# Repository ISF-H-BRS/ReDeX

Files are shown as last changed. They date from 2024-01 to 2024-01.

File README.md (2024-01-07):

# ReDeX: Water Purification Measurements

## Introduction

This repository contains a public archive of electronics, firmware and software developed as part of the project [ReDeX](https://www.h-brs.de/de/entwicklung-einer-reduktiven-behandlungsmethode-zur-entfernung-von-desinfektionsnebenprodukten-und) that was conducted at Bonn-Rhein-Sieg University of Applied Sciences from 2019 to 2022.

The goal of this sub-project was to develop a sensor network allowing various parameters inside a water purification system to be monitored and analyzed in order to gain a better understanding of the chemical and physical processes involved.

The system is composed of sensor nodes which can be used either as standalone devices connected to a PC over USB or as a sensor network accessed over TCP/IP via a central hub. Every sensor provides complete galvanic isolation in order to prevent any possibility of cross-currents which could potentially invalidate measurements.

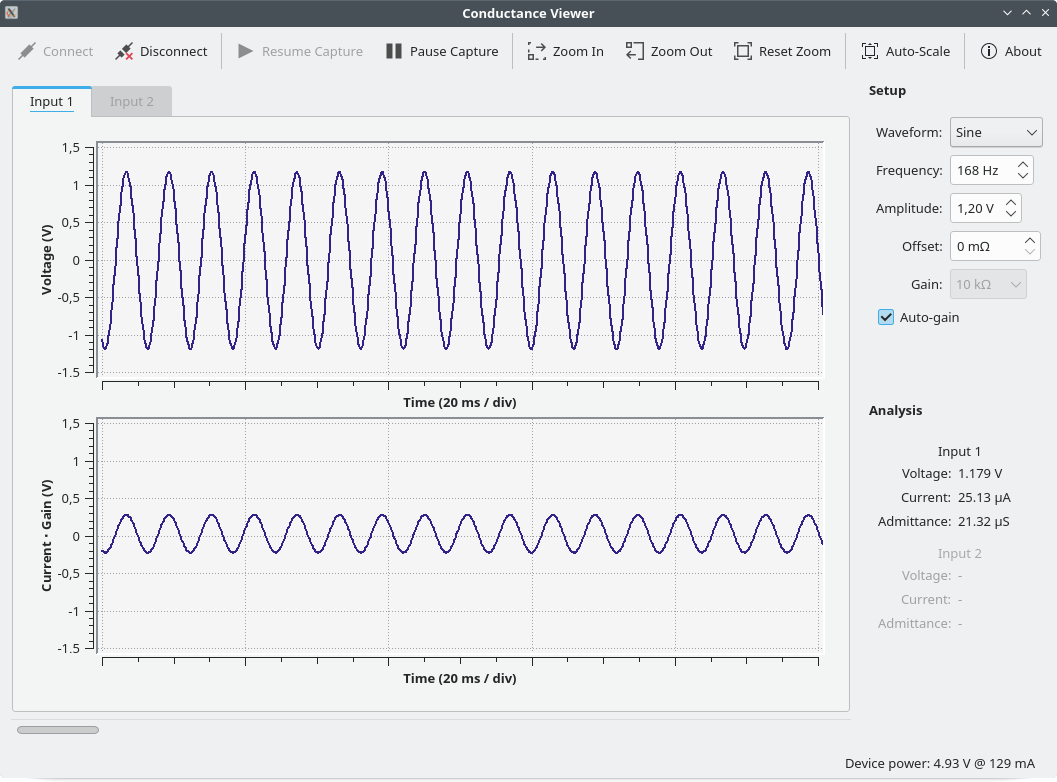
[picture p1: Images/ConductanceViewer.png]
ConductanceViewer


The parameters that can be measured include conductance, pH/ORP levels and temperature. In addition a potentiostat for cyclic voltammetry was developed, providing a compliance voltage of ±4 V and a dynamic range of approx. 1 pA to 10 mA.

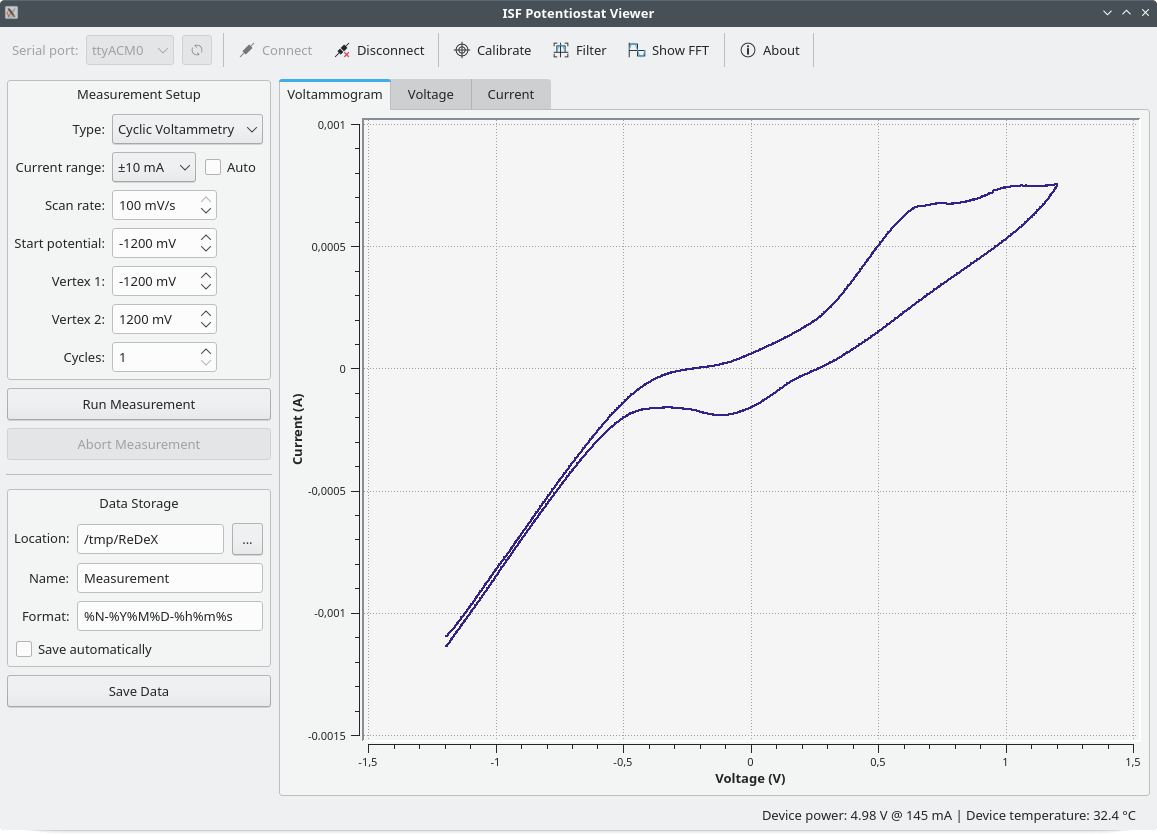
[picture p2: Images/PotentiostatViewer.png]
PotentiostatViewer


Every sensor node has a corresponding user software providing a GUI for individual measurements. The complete sensor network can be accessed via the central hub by means of a shared library with optional LabVIEW integration.

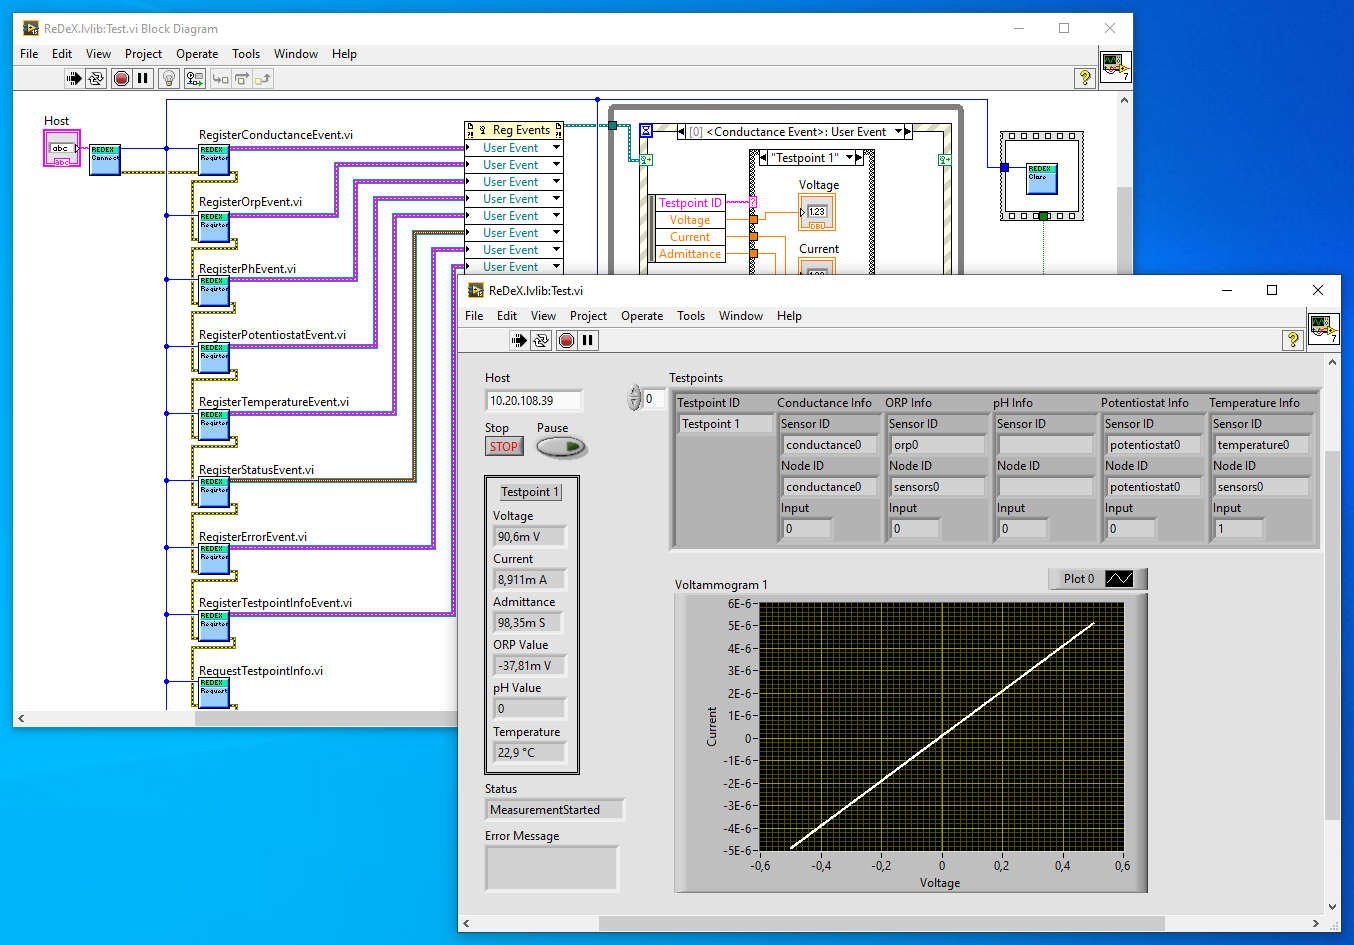
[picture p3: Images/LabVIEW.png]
LabVIEW


## License

All source code for the software and firmware components (including the LabVIEW code) is licensed under the terms of the GNU General Public License (GPL). All schematics and CAD files for EAGLE and FreeCAD are licensed under the terms of the Creative Commons Attribution-ShareAlike International Public License (CC BY-SA). See COPYING in the respective subdirectories for details.

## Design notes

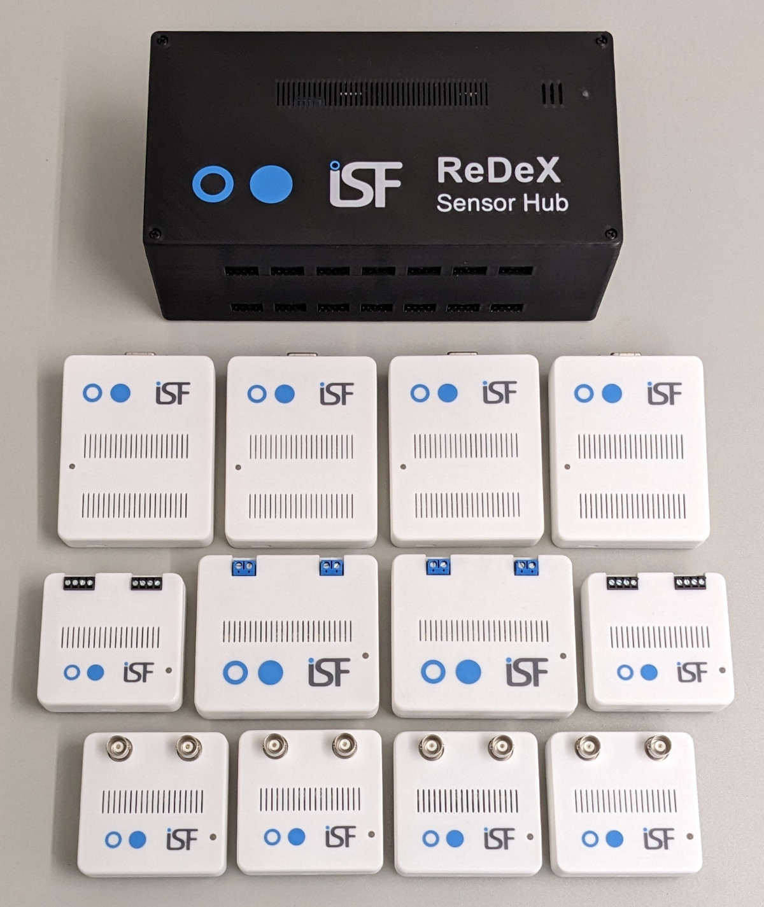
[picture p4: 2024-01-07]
Images/Overview.jpg

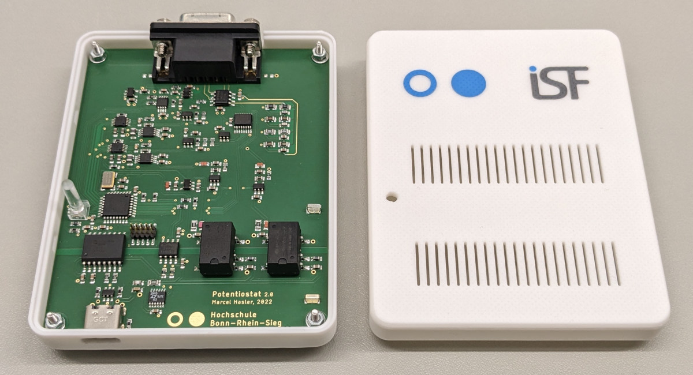
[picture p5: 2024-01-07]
Images/Potentiostat2.jpg

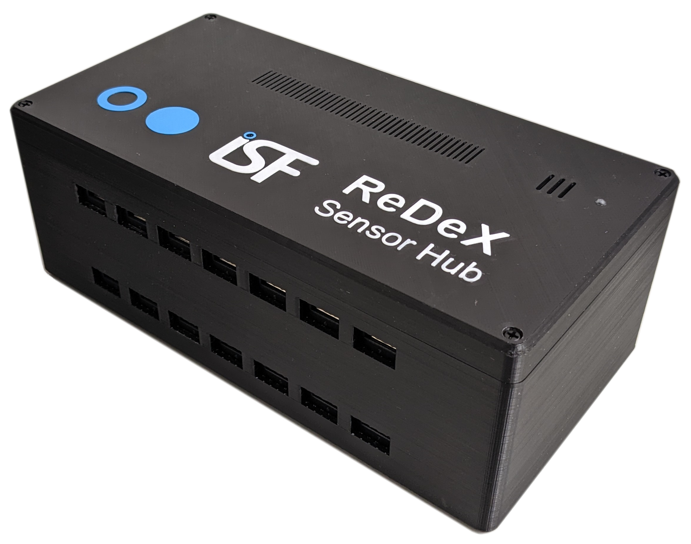
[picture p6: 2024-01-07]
Images/HubFront.jpg

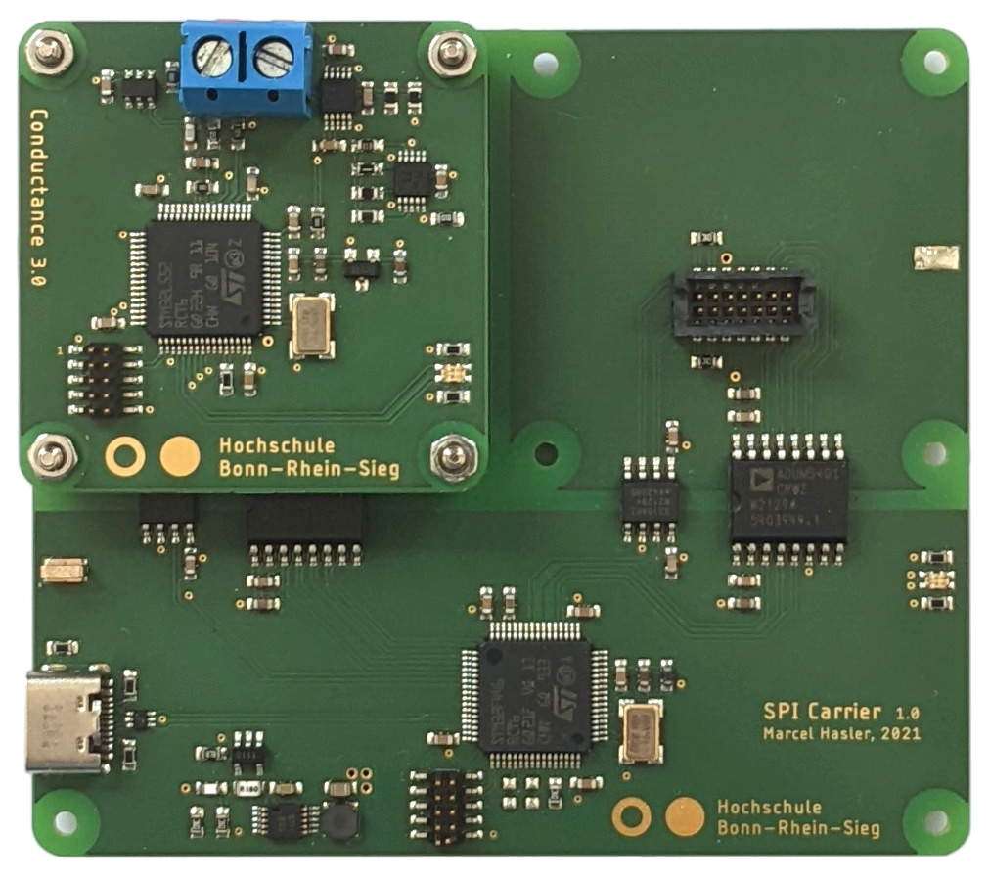
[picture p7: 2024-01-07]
Images/ConductanceBoard.jpg

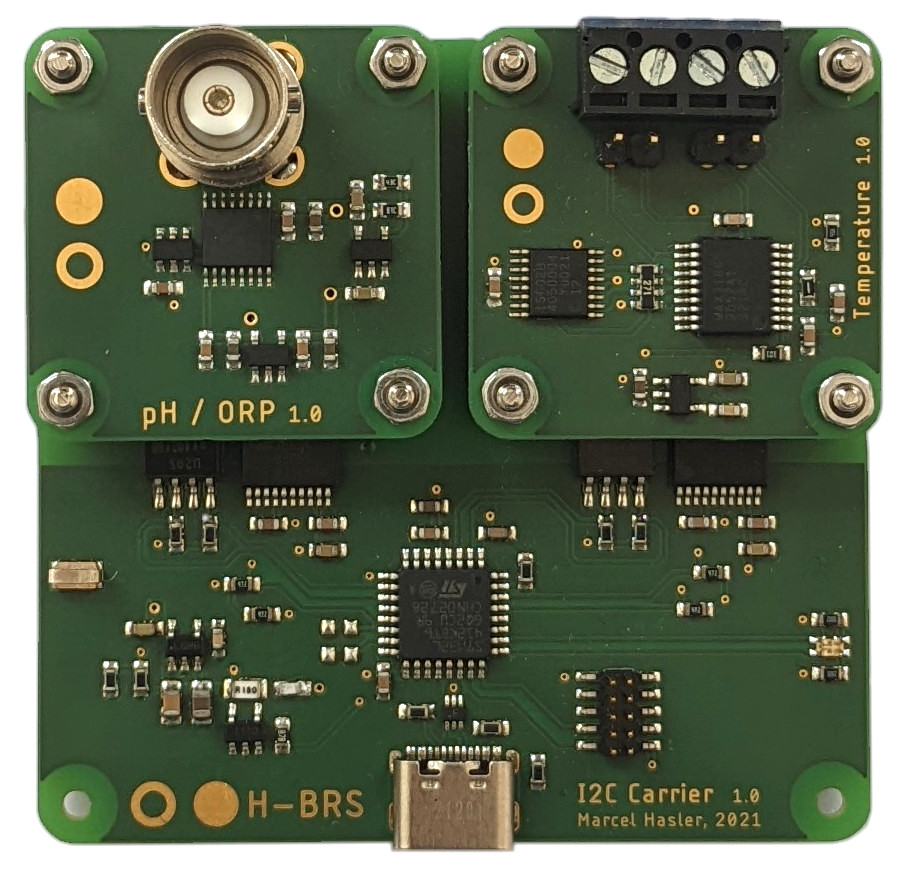
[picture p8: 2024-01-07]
Images/SensorBoard.jpg

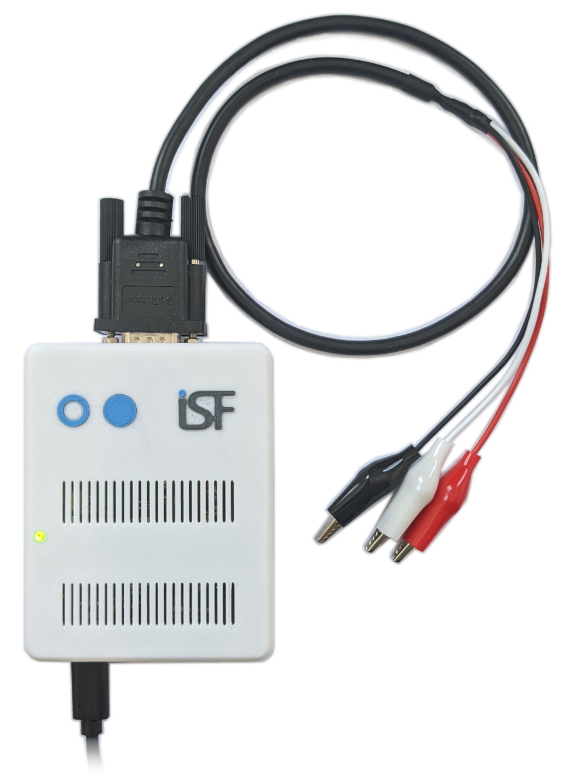
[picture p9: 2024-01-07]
Images/Potentiostat1.jpg

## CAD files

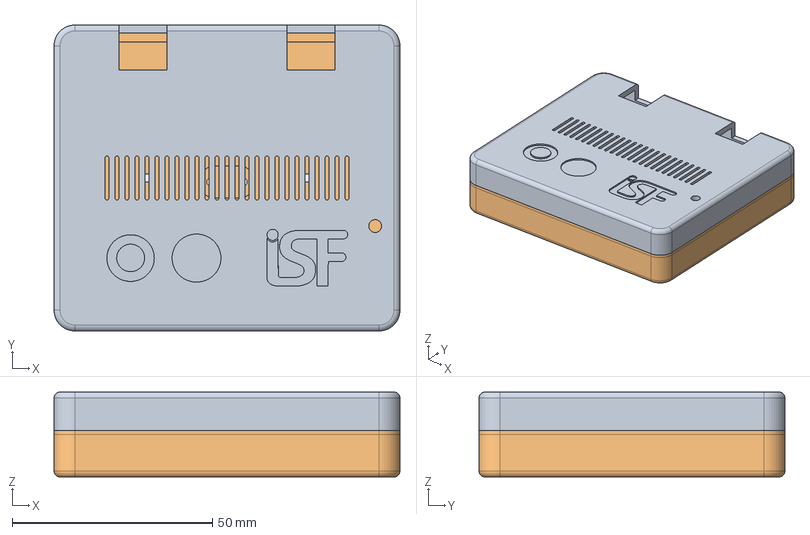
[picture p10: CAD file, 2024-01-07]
FreeCAD/Conductance/Conductance.FCStd
86.4 x 76.4 x 21.2 mm
TopLogosCut
BottomMountholeCut

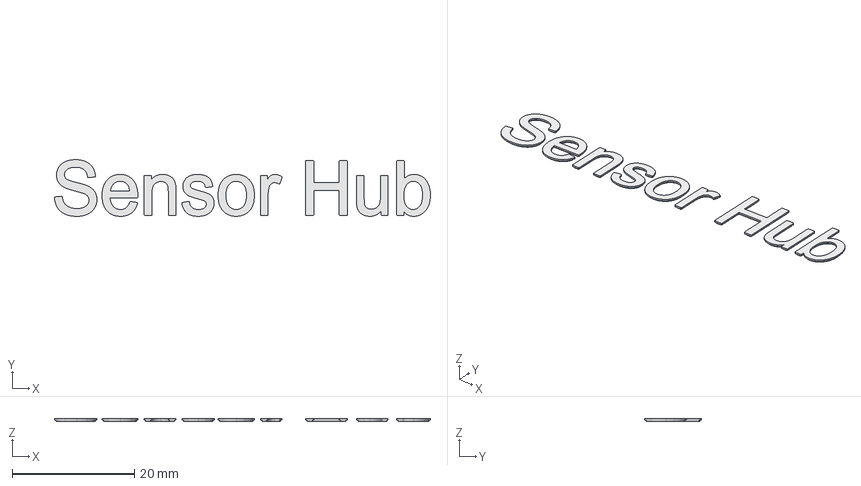
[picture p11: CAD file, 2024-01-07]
FreeCAD/Hub/Label.FCStd
61.5 x 9.29 x 0.48 mm

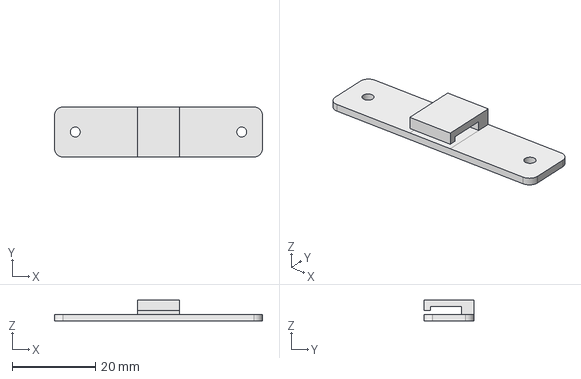
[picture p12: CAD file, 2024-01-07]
FreeCAD/Other/NodeMount.FCStd
50.0 x 12.0 x 5.00 mm

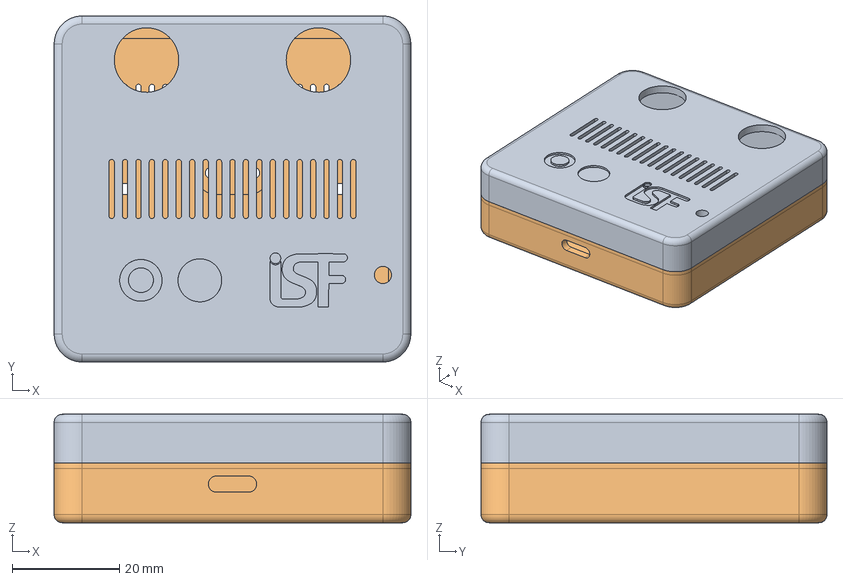
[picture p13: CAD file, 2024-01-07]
FreeCAD/pH/pH.FCStd
66.4 x 64.4 x 20.2 mm
TopLogosCut
BottomLockCut

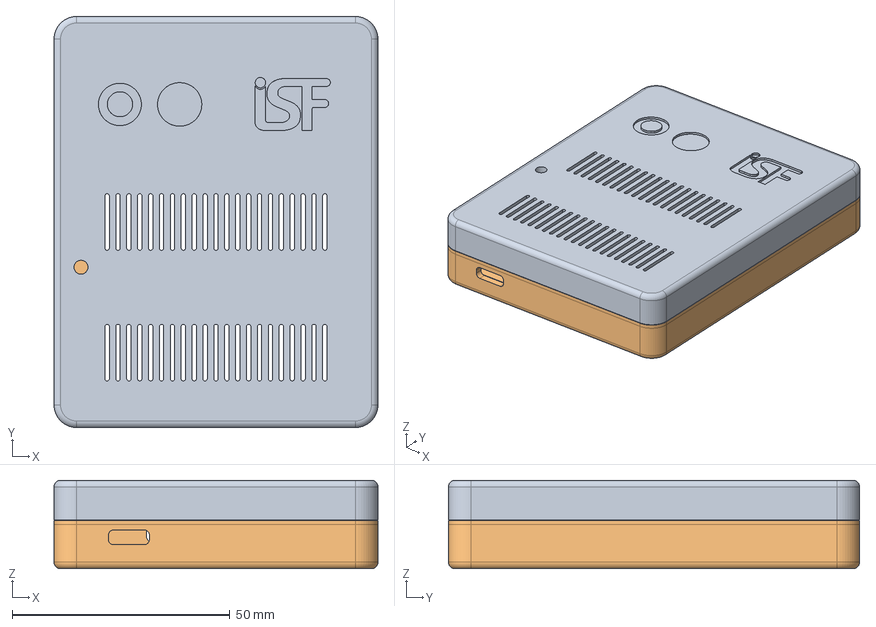
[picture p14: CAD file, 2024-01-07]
FreeCAD/Potentiostat/Potentiostat.FCStd
74.4 x 94.4 x 20.3 mm
TopLogosCut
BottomMountholeCut

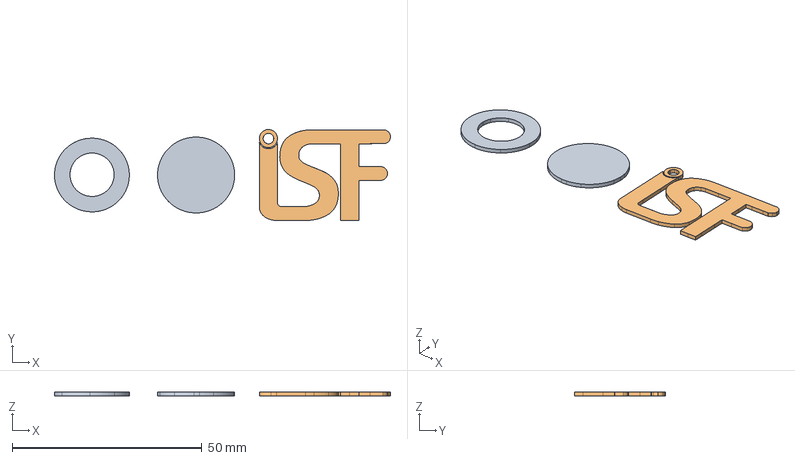
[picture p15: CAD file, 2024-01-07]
FreeCAD/Hub/Logos.FCStd
88.6 x 24.0 x 1.00 mm
H-BRS
ISF

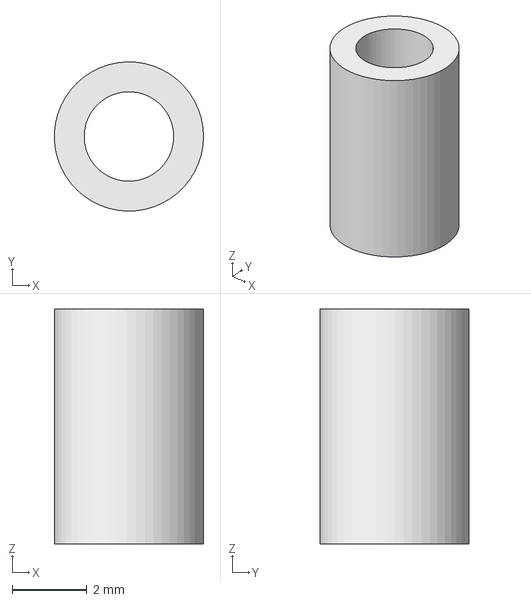
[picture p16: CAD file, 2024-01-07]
FreeCAD/Other/Tube.FCStd
4.00 x 4.00 x 6.30 mm

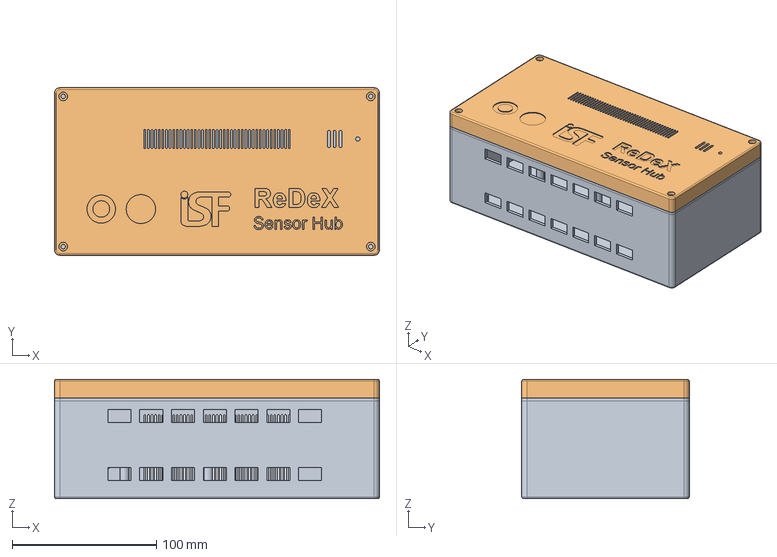
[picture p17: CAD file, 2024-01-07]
FreeCAD/Hub/Hub.FCStd
225.0 x 116.0 x 82.5 mm
BottomBody
TopEngravingsCut

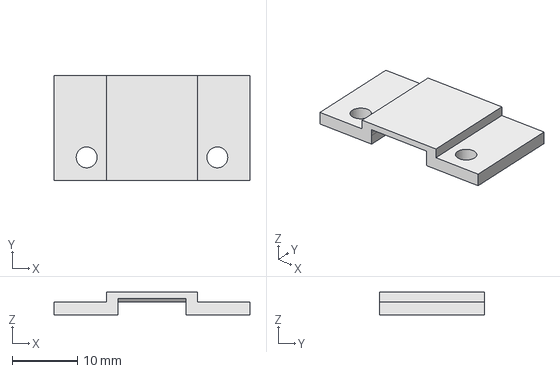
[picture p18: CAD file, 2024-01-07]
FreeCAD/Other/NodeHolder.FCStd
30.0 x 16.0 x 3.50 mm

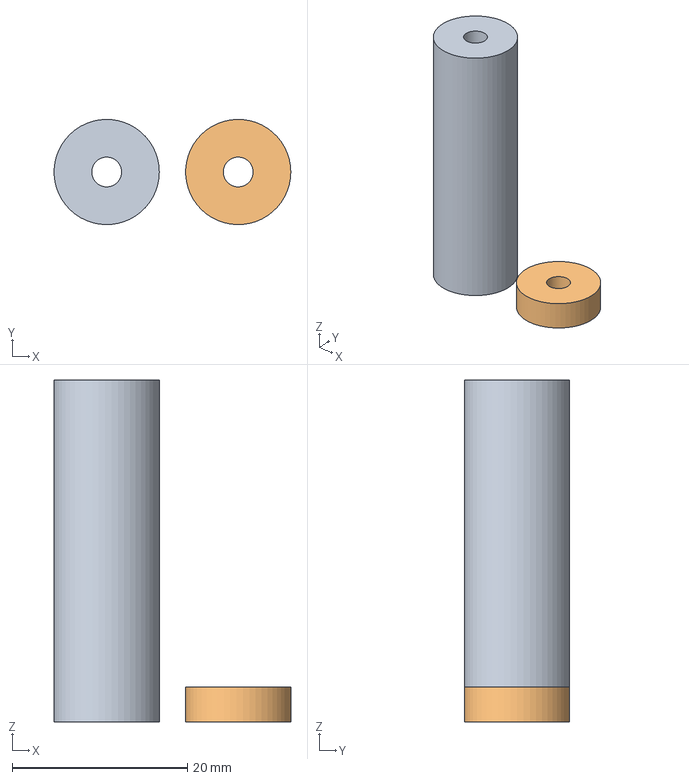
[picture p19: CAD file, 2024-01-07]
FreeCAD/Hub/Spacer.FCStd
27.0 x 12.0 x 39.0 mm
Long
Short

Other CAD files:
FreeCAD/SensorBoard/SensorBoard.FCStd
FreeCAD/Temperature/Temperature.FCStd

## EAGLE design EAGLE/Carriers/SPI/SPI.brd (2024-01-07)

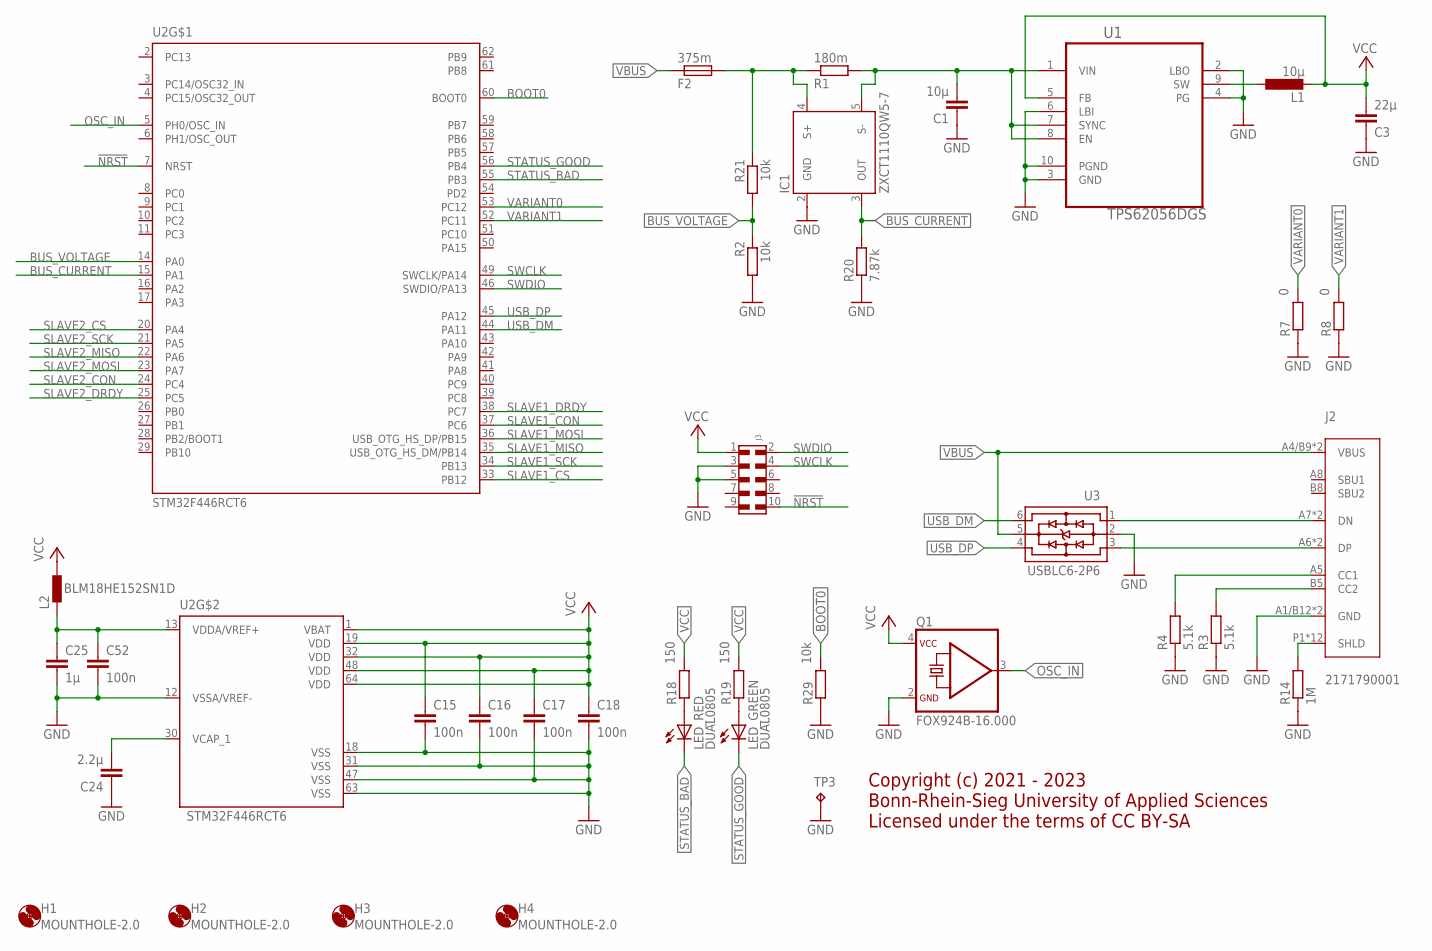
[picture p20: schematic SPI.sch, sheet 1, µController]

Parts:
C1: 10µ; C0603
C3: 22µ; C0603
C15, C16, C17, C18, C52: 100n; C0603
C24: 2.2µ; C0603
C25: 1µ; C0603
F2: 375m; R0603
H1, H2, H3, H4: MOUNTHOLE-2.0; 2.0
IC1: ZXCT1110QW5-7; SOT23-5L
J2: 2171790001; 2171790001_MOL
J3: 6210XX21021_62101021021; 62101021021
L1: 10µ; 2SMD
L2: BLM18HE152SN1D; 0603
LED_: DUAL0805; CHIPLEDX2
Q1: FOX924B-16.000; FOX924B
R1: 180m; R0603
R2, R21, R29: 10k; R0603
R3, R4: 5.1k; R0603
R7, R8: 0; R0603
R14: 1M; R0603
R18, R19: 150; R0603
R20: 7.87k; R0603
TP3: TP3.8X2.03; 3.8X2.03
U1: TPS62056DGS; SOP50P490X110-10N
U2: STM32F446RCT6; LQFP64
U3: USBLC6-2P6; SOT-666

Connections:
!NRST: J3.10, U2.7 (NRST)
BOOT0: R29.2, U2.60 (BOOT0)
BUS_CURRENT: IC1.3 (OUT), R20.2, U2.15 (PA1)
BUS_VOLTAGE: R2.1, R21.2, U2.14 (PA0)
GND: C1.1, C3.1, C15.2, C16.2, C17.2, C18.2, C24.1, C25.2, C52.2, IC1.2 (GND), J2.A1/B12 (GND), J2.B1/A12 (GND), J3.3, J3.5, Q1.2 (GND), R2.2, R3.1, R4.1, R7.1, R8.1, R14.1, R20.1, R29.1, TP3.TP, U1.2 (LBO), U1.3 (GND), U1.4 (PG), U1.6 (LBI), U1.10 (PGND), U2.12 (VSSA/VREF-), U2.18 (VSS), U2.31 (VSS), U2.47 (VSS), U2.63 (VSS), U3.2; also elsewhere on the board
unnamed: J2.P1 (SHLD), J2.P2 (SHLD), J2.P3 (SHLD), J2.P4 (SHLD), J2.S1 (SHLD), J2.S2 (SHLD), J2.S3 (SHLD), J2.S4 (SHLD), J2.S5 (SHLD), J2.S6 (SHLD), J2.S7 (SHLD), J2.S8 (SHLD), R14.2
unnamed: C1.2, IC1.5 (S-), R1.2, U1.1 (VIN), U1.7 (SYNC), U1.8 (EN)
unnamed: L1.P$1 (1), U1.9 (SW)
unnamed: J2.A6 (DP), J2.B6 (DP), U3.3
unnamed: J2.A7 (DN), J2.B7 (DN), U3.1
unnamed: J2.B5 (CC2), R3.2
unnamed: J2.A5 (CC1), R4.2
unnamed: C25.1, C52.1, L2.2, U2.13 (VDDA/VREF+)
unnamed: F2.2, IC1.4 (S+), R1.1, R21.1
unnamed: C24.2, U2.30 (VCAP_1)
unnamed: LED_.A1 (A), R18.1
unnamed: LED_.A2 (A), R19.1
OSC_IN: Q1.3 (OUT), U2.5 (PH0/OSC_IN)
SLAVE1_CON: U2.37 (PC6); also elsewhere on the board
SLAVE1_CS: U2.33 (PB12); also elsewhere on the board
SLAVE1_DRDY: U2.38 (PC7); also elsewhere on the board
SLAVE1_MISO: U2.35 (USB_OTG_HS_DM/PB14); also elsewhere on the board
SLAVE1_MOSI: U2.36 (USB_OTG_HS_DP/PB15); also elsewhere on the board
SLAVE1_SCK: U2.34 (PB13); also elsewhere on the board
SLAVE2_CON: U2.24 (PC4); also elsewhere on the board
SLAVE2_CS: U2.20 (PA4); also elsewhere on the board
SLAVE2_DRDY: U2.25 (PC5); also elsewhere on the board
SLAVE2_MISO: U2.22 (PA6); also elsewhere on the board
SLAVE2_MOSI: U2.23 (PA7); also elsewhere on the board
SLAVE2_SCK: U2.21 (PA5); also elsewhere on the board
STATUS_BAD: LED_.C1 (C), U2.55 (PB3)
STATUS_GOOD: LED_.C2 (C), U2.56 (PB4)
SWCLK: J3.4, U2.49 (SWCLK/PA14)
SWDIO: J3.2, U2.46 (SWDIO/PA13)
USB_DM: U2.44 (PA11), U3.6
USB_DP: U2.45 (PA12), U3.4
VARIANT0: R7.2, U2.53 (PC12)
VARIANT1: R8.2, U2.52 (PC11)
VBUS: F2.1, J2.A4/B9 (VBUS), J2.B4/A9 (VBUS), U3.5
VCC: C3.2, C15.1, C16.1, C17.1, C18.1, J3.1, L1.P$2 (2), L2.1, Q1.4 (VCC), R18.2, R19.2, U1.5 (FB), U2.1 (VBAT), U2.19 (VDD), U2.32 (VDD), U2.48 (VDD), U2.64 (VDD); also elsewhere on the board

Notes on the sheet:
Copyright (c) 2021 - 2023 Bonn-Rhein-Sieg University of Applied Sciences Licensed under the terms of CC BY-SA

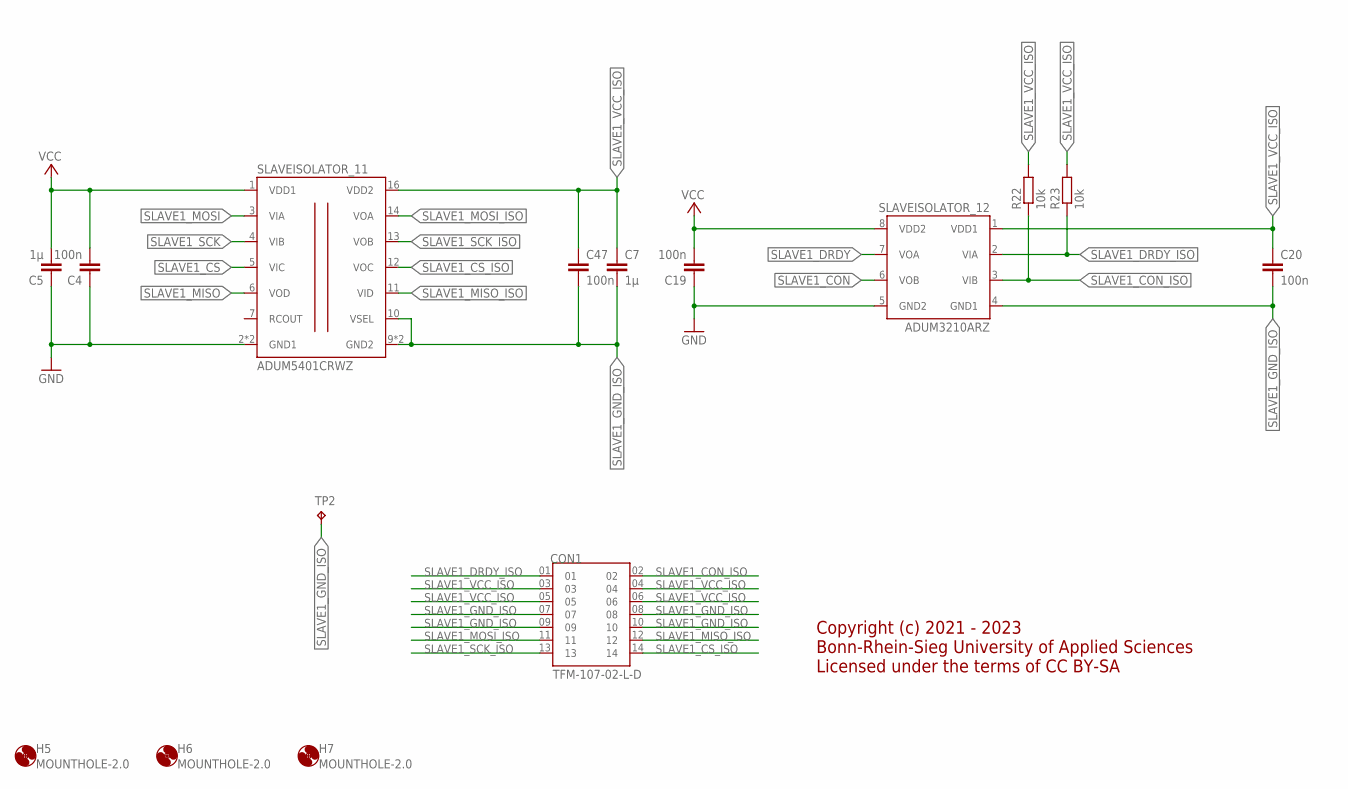
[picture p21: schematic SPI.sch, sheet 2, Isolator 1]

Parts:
C4, C19, C20, C47: 100n; C0603
C5, C7: 1µ; C0603
CON1: TFM-107-02-L-D; SAMTEC_TFM-107-02-L-D
H5, H6, H7: MOUNTHOLE-2.0; 2.0
R22, R23: 10k; R0603
SLAVEISOLATOR_11: ADUM5401CRWZ; SO16W
SLAVEISOLATOR_12: ADUM3210ARZ; SOIC8
TP2: TP3.8X2.03; 3.8X2.03

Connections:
GND: C4.1, C5.1, C19.1, SLAVEISOLATOR_11.2 (GND1), SLAVEISOLATOR_11.8 (GND1), SLAVEISOLATOR_12.5 (GND2); also elsewhere on the board
SLAVE1_CON: SLAVEISOLATOR_12.6 (VOB); also elsewhere on the board
SLAVE1_CON_ISO: CON1.02, R22.1, SLAVEISOLATOR_12.3 (VIB)
SLAVE1_CS: SLAVEISOLATOR_11.5 (VIC); also elsewhere on the board
SLAVE1_CS_ISO: CON1.14, SLAVEISOLATOR_11.12 (VOC)
SLAVE1_DRDY: SLAVEISOLATOR_12.7 (VOA); also elsewhere on the board
SLAVE1_DRDY_ISO: CON1.01, R23.1, SLAVEISOLATOR_12.2 (VIA)
SLAVE1_GND_ISO: C7.2, C20.2, C47.2, CON1.07, CON1.08, CON1.09, CON1.10, SLAVEISOLATOR_11.9 (GND2), SLAVEISOLATOR_11.10 (VSEL), SLAVEISOLATOR_11.15 (GND2), SLAVEISOLATOR_12.4 (GND1), TP2.TP
SLAVE1_MISO: SLAVEISOLATOR_11.6 (VOD); also elsewhere on the board
SLAVE1_MISO_ISO: CON1.12, SLAVEISOLATOR_11.11 (VID)
SLAVE1_MOSI: SLAVEISOLATOR_11.3 (VIA); also elsewhere on the board
SLAVE1_MOSI_ISO: CON1.11, SLAVEISOLATOR_11.14 (VOA)
SLAVE1_SCK: SLAVEISOLATOR_11.4 (VIB); also elsewhere on the board
SLAVE1_SCK_ISO: CON1.13, SLAVEISOLATOR_11.13 (VOB)
SLAVE1_VCC_ISO: C7.1, C20.1, C47.1, CON1.03, CON1.04, CON1.05, CON1.06, R22.2, R23.2, SLAVEISOLATOR_11.16 (VDD2), SLAVEISOLATOR_12.1 (VDD1)
VCC: C4.2, C5.2, C19.2, SLAVEISOLATOR_11.1 (VDD1), SLAVEISOLATOR_12.8 (VDD2); also elsewhere on the board

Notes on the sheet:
Copyright (c) 2021 - 2023 Bonn-Rhein-Sieg University of Applied Sciences Licensed under the terms of CC BY-SA

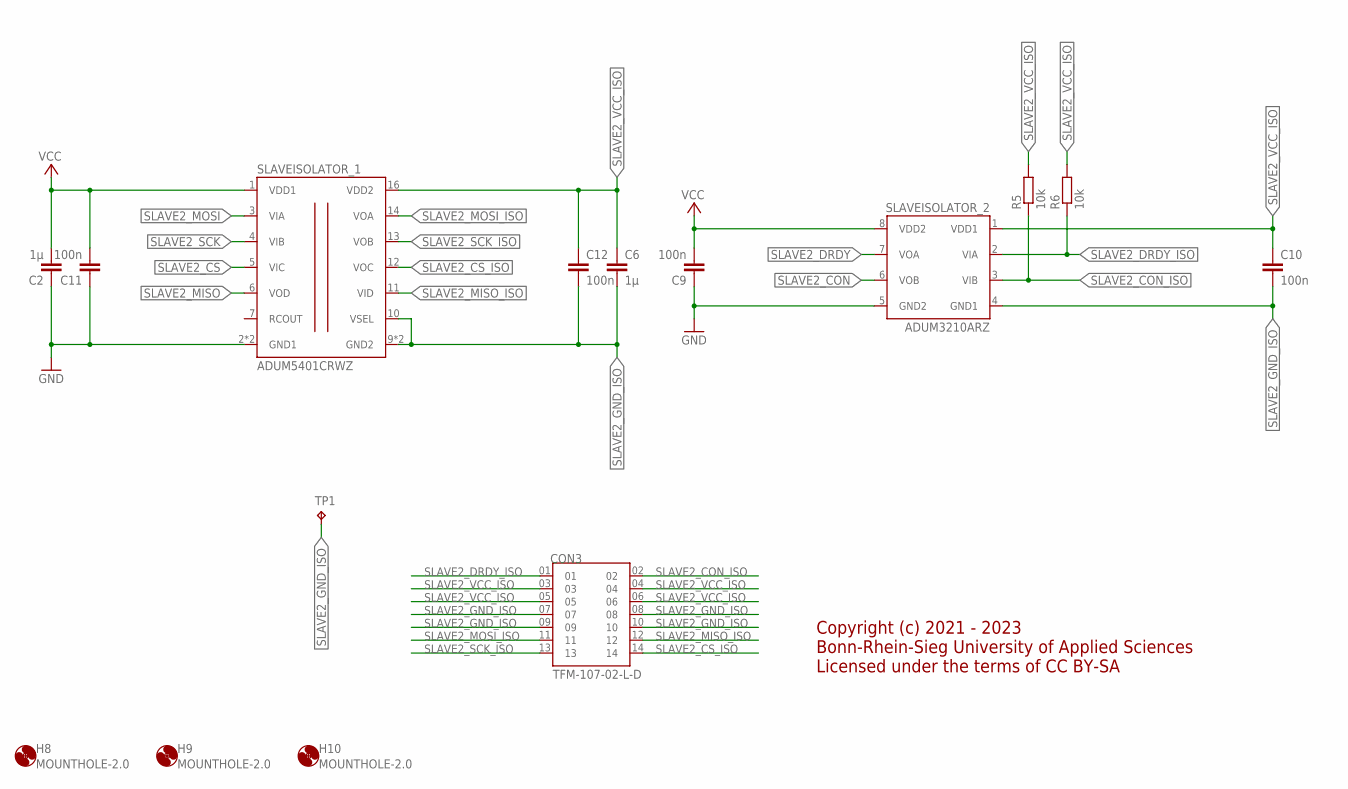
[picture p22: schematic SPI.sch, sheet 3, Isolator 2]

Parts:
C2, C6: 1µ; C0603
C9, C10, C11, C12: 100n; C0603
CON3: TFM-107-02-L-D; SAMTEC_TFM-107-02-L-D
H8, H9, H10: MOUNTHOLE-2.0; 2.0
R5, R6: 10k; R0603
SLAVEISOLATOR_1: ADUM5401CRWZ; SO16W
SLAVEISOLATOR_2: ADUM3210ARZ; SOIC8
TP1: TP3.8X2.03; 3.8X2.03

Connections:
GND: C2.1, C9.1, C11.1, SLAVEISOLATOR_1.2 (GND1), SLAVEISOLATOR_1.8 (GND1), SLAVEISOLATOR_2.5 (GND2); also elsewhere on the board
SLAVE2_CON: SLAVEISOLATOR_2.6 (VOB); also elsewhere on the board
SLAVE2_CON_ISO: CON3.02, R5.1, SLAVEISOLATOR_2.3 (VIB)
SLAVE2_CS: SLAVEISOLATOR_1.5 (VIC); also elsewhere on the board
SLAVE2_CS_ISO: CON3.14, SLAVEISOLATOR_1.12 (VOC)
SLAVE2_DRDY: SLAVEISOLATOR_2.7 (VOA); also elsewhere on the board
SLAVE2_DRDY_ISO: CON3.01, R6.1, SLAVEISOLATOR_2.2 (VIA)
SLAVE2_GND_ISO: C6.2, C10.2, C12.2, CON3.07, CON3.08, CON3.09, CON3.10, SLAVEISOLATOR_1.9 (GND2), SLAVEISOLATOR_1.10 (VSEL), SLAVEISOLATOR_1.15 (GND2), SLAVEISOLATOR_2.4 (GND1), TP1.TP
SLAVE2_MISO: SLAVEISOLATOR_1.6 (VOD); also elsewhere on the board
SLAVE2_MISO_ISO: CON3.12, SLAVEISOLATOR_1.11 (VID)
SLAVE2_MOSI: SLAVEISOLATOR_1.3 (VIA); also elsewhere on the board
SLAVE2_MOSI_ISO: CON3.11, SLAVEISOLATOR_1.14 (VOA)
SLAVE2_SCK: SLAVEISOLATOR_1.4 (VIB); also elsewhere on the board
SLAVE2_SCK_ISO: CON3.13, SLAVEISOLATOR_1.13 (VOB)
SLAVE2_VCC_ISO: C6.1, C10.1, C12.1, CON3.03, CON3.04, CON3.05, CON3.06, R5.2, R6.2, SLAVEISOLATOR_1.16 (VDD2), SLAVEISOLATOR_2.1 (VDD1)
VCC: C2.2, C9.2, C11.2, SLAVEISOLATOR_1.1 (VDD1), SLAVEISOLATOR_2.8 (VDD2); also elsewhere on the board

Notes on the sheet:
Copyright (c) 2021 - 2023 Bonn-Rhein-Sieg University of Applied Sciences Licensed under the terms of CC BY-SA

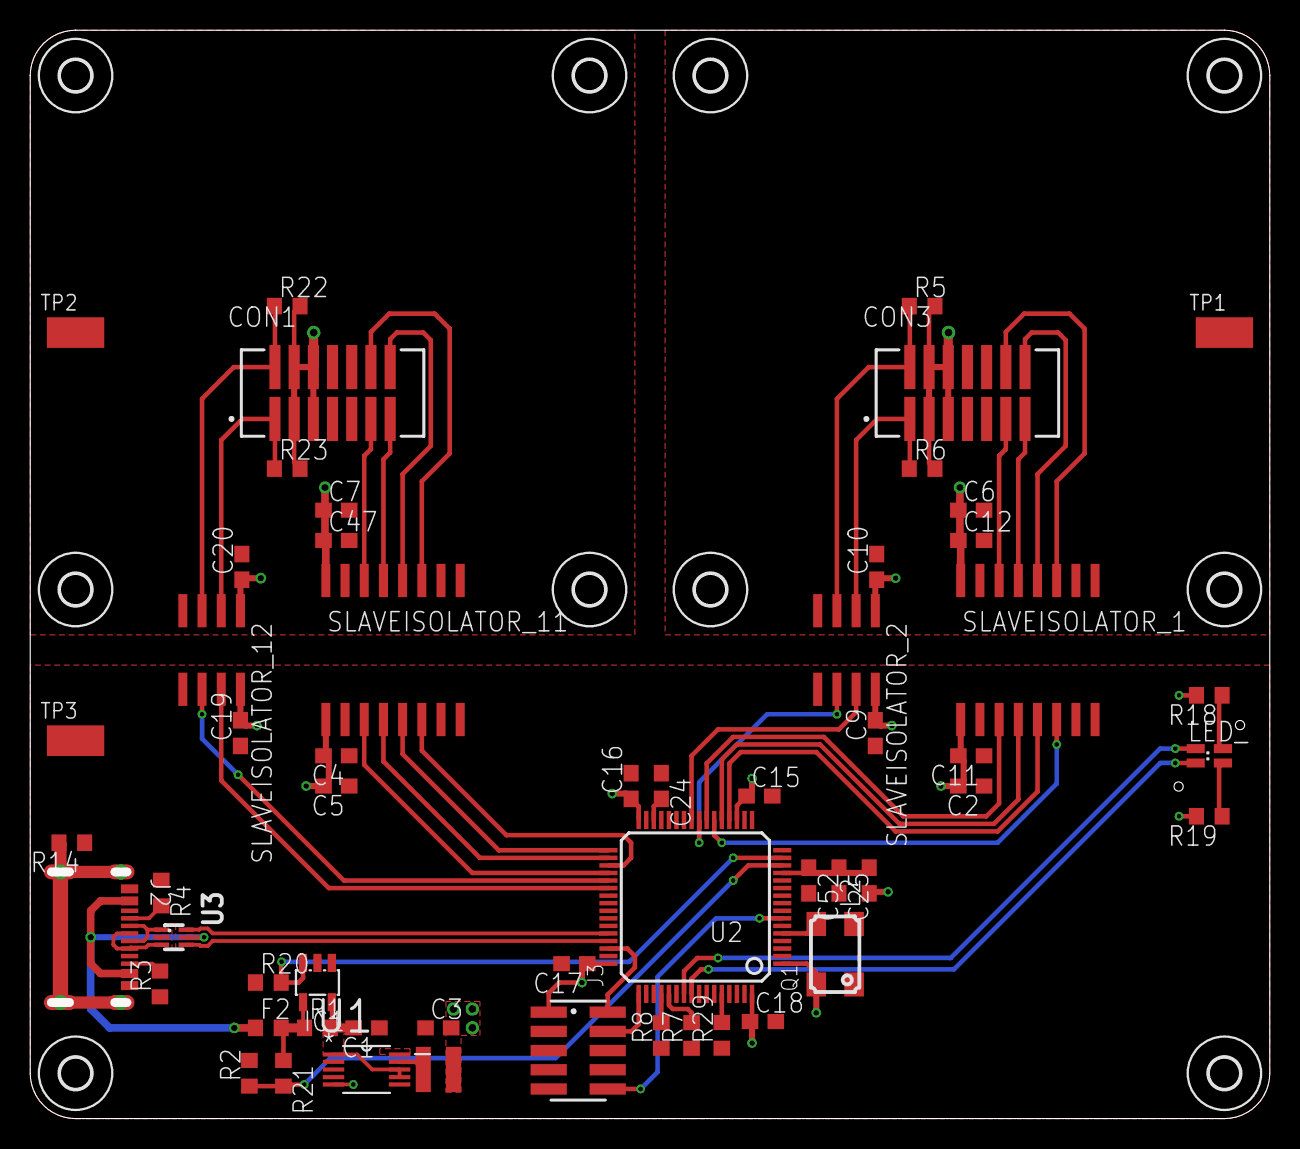
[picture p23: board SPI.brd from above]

Board: 2 copper layers, 82.0 x 72.0 mm, 67 parts (0 on the bottom side), 56 nets.

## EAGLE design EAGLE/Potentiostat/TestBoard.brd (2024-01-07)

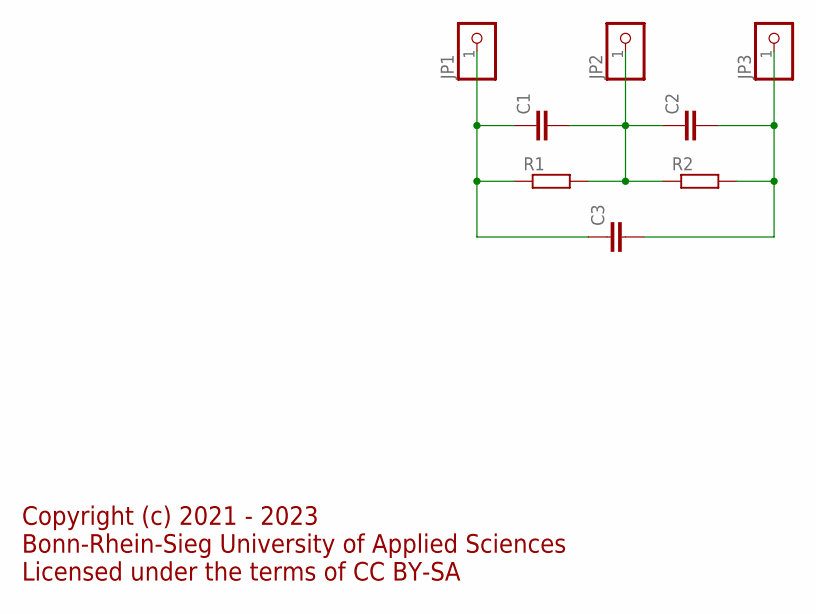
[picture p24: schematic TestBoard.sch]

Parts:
C1, C2, C3: C-EUC0603; C0603
JP1, JP2, JP3: PINHD-1X1; 1X01
R1, R2: R-EU_R0603; R0603

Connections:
unnamed: C1.1, C3.1, JP1.1, R1.1
unnamed: C1.2, C2.1, JP2.1, R1.2, R2.1
unnamed: C2.2, C3.2, JP3.1, R2.2

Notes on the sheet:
Copyright (c) 2021 - 2023 Bonn-Rhein-Sieg University of Applied Sciences Licensed under the terms of CC BY-SA

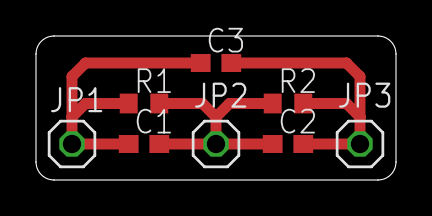
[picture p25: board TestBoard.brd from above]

Board: 2 copper layers, 20.0 x 8.0 mm, 8 parts (0 on the bottom side), 3 nets.

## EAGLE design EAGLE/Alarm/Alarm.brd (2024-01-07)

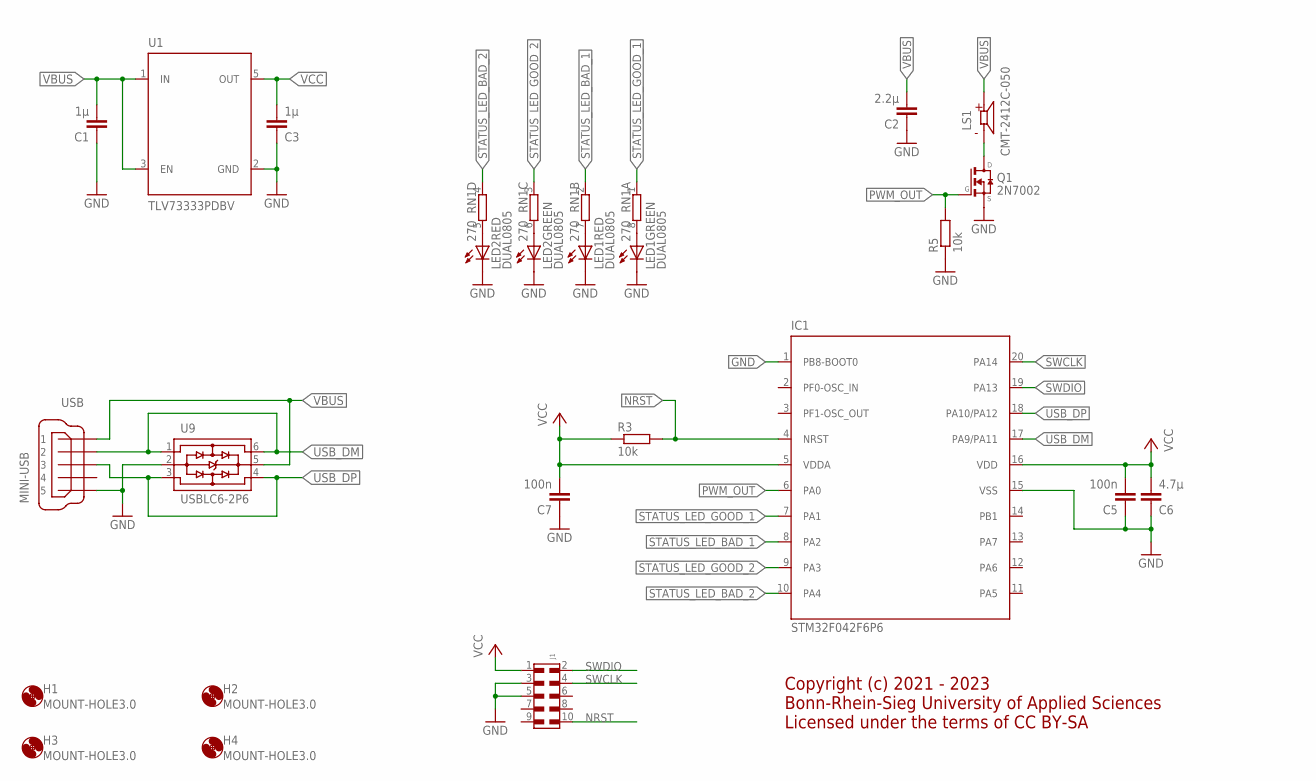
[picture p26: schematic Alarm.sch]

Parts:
C1, C3: 1µ; C0603
C2: 2.2µ; C0603
C5, C7: 100n; C0603
C6: 4.7µ; C0603
H1, H2, H3, H4: MOUNT-HOLE3.0; 3,0
IC1: STM32F042F6P6; TSSOP20
J1: 6210XX21021_62101021021; 62101021021
LED1, LED2: DUAL0805; CHIPLEDX2
LS1: CMT-2412C-050; CUI_CMT-2412C-050
Q1: 2N7002; SOT23
R3, R5: 10k; R0603
RN1: 270; EXB38V
U1: TLV73333PDBV; SOT-23
U9: USBLC6-2P6; SOT-666; PARTNO *
USB: MINI-USB; 32005-201

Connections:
GND: C1.1, C2.1, C3.1, C5.1, C6.1, C7.1, IC1.1 (PB8-BOOT0), IC1.15 (VSS), J1.3, J1.5, LED1.C1 (C), LED1.C2 (C), LED2.C1 (C), LED2.C2 (C), Q1.2 (S), R5.1, U1.2 (GND), U9.2, USB.5
unnamed: LED2.A1 (A), RN1.5 (2)
unnamed: LED2.A2 (A), RN1.6 (2)
unnamed: LED1.A1 (A), RN1.7 (2)
unnamed: LED1.A2 (A), RN1.8 (2)
unnamed: LS1.N, Q1.3 (D)
NRST: IC1.4 (NRST), J1.10, R3.2
PWM_OUT: IC1.6 (PA0), Q1.1 (G), R5.2
STATUS_LED_BAD_1: IC1.8 (PA2), RN1.2 (1)
STATUS_LED_BAD_2: IC1.10 (PA4), RN1.4 (1)
STATUS_LED_GOOD_1: IC1.7 (PA1), RN1.1
STATUS_LED_GOOD_2: IC1.9 (PA3), RN1.3 (1)
SWCLK: IC1.20 (PA14), J1.4
SWDIO: IC1.19 (PA13), J1.2
USB_DM: IC1.17 (PA9/PA11), U9.1, U9.6, USB.2
USB_DP: IC1.18 (PA10/PA12), U9.3, U9.4, USB.3
VBUS: C1.2, C2.2, LS1.P, U1.1 (IN), U1.3 (EN), U9.5, USB.1
VCC: C3.2, C5.2, C6.2, C7.2, IC1.5 (VDDA), IC1.16 (VDD), J1.1, R3.1, U1.5 (OUT)

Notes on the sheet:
Copyright (c) 2021 - 2023 Bonn-Rhein-Sieg University of Applied Sciences Licensed under the terms of CC BY-SA

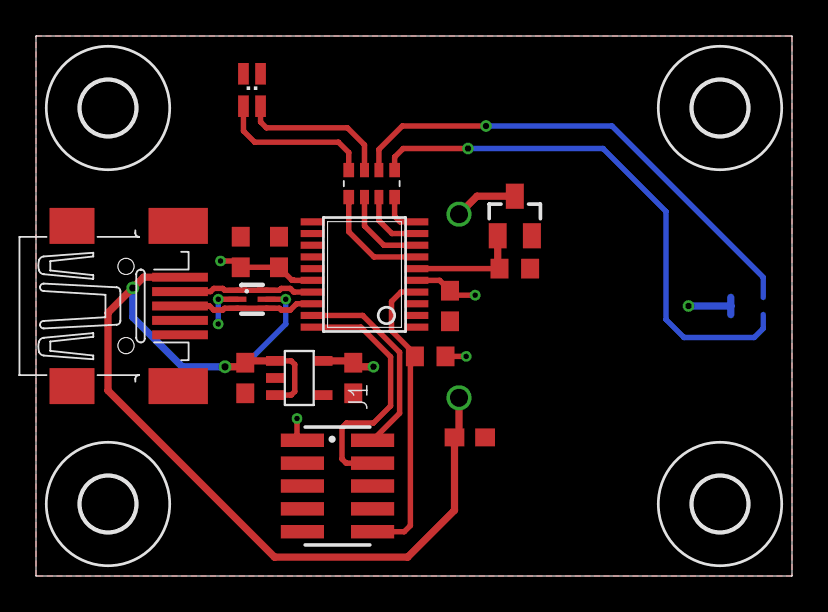
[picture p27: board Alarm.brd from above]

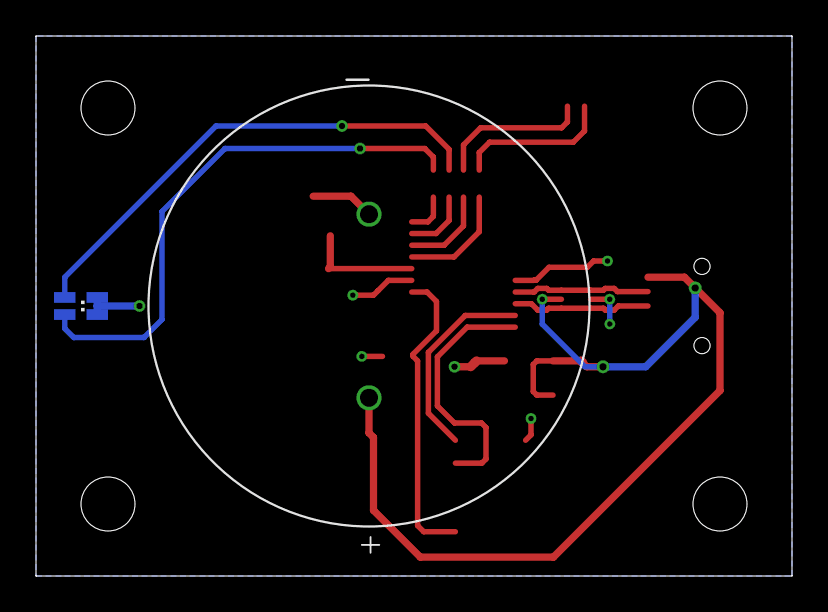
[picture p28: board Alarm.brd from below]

Board: 2 copper layers, 42.0 x 30.0 mm, 22 parts (2 on the bottom side), 18 nets.

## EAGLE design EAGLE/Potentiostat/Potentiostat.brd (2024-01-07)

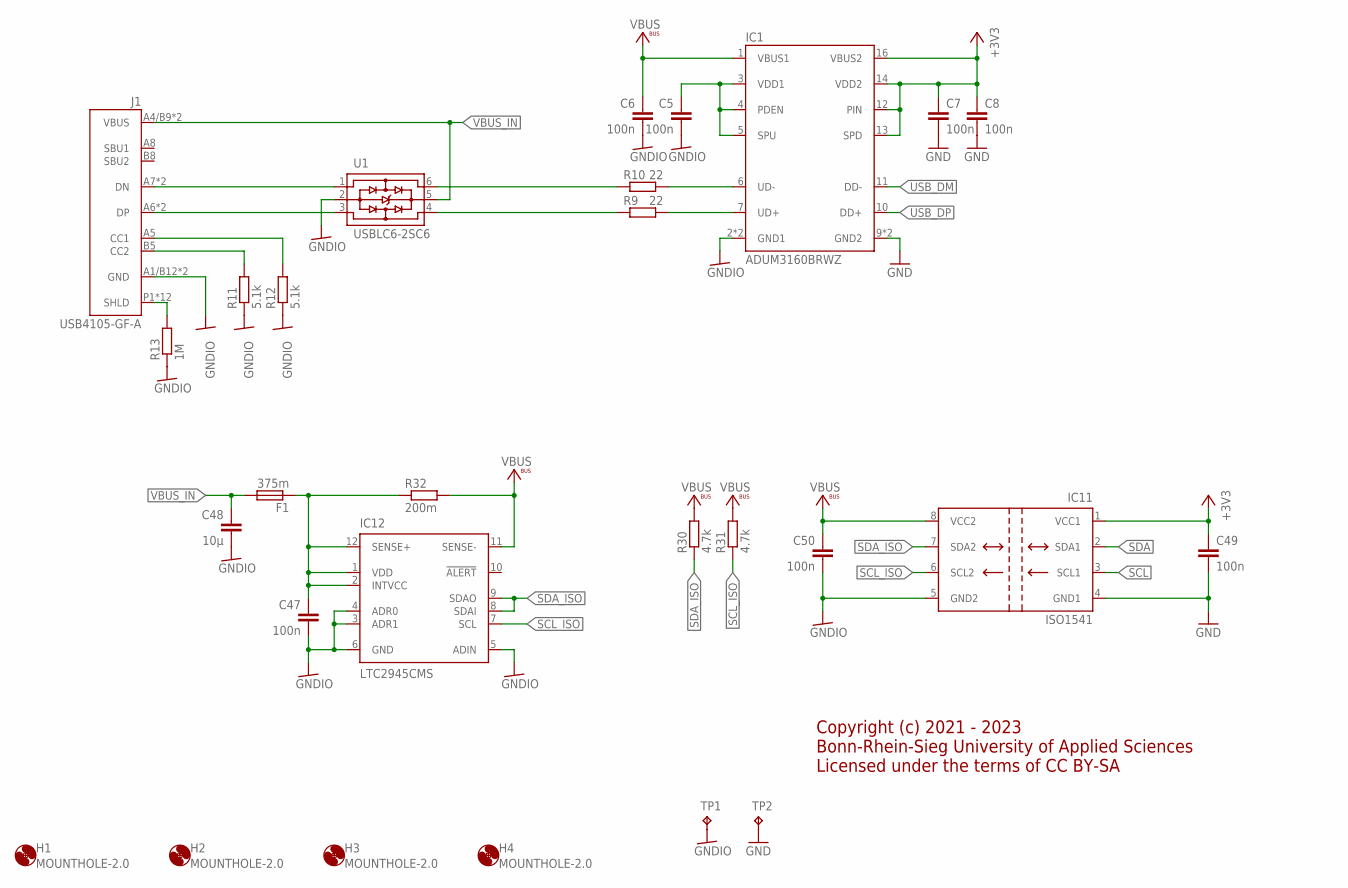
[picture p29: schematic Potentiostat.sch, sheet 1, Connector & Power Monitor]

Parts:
C5, C6, C7, C8, C47, C49, C50: 100n; C0603
C48: 10µ; C0603
F1: 375m; R0603
H1, H2, H3, H4: MOUNTHOLE-2.0; 2.0
IC1: ADUM3160BRWZ; SO16W
IC11: ISO1541; SOIC8
IC12: LTC2945CMS; MSOP12
J1: USB4105-GF-A
R9, R10: 22; R0603
R11, R12: 5.1k; R0603
R13: 1M; R0603
R30, R31: 4.7k; R0603
R32: 200m; R0805
TP1, TP2: TP3.8X2.03; 3.8X2.03
U1: USBLC6-2SC6; SOT23-6L

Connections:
+3V3: C7.1, C8.1, C49.1, IC1.12 (PIN), IC1.13 (SPD), IC1.14 (VDD2), IC1.16 (VBUS2), IC11.1 (VCC1); also elsewhere on the board
GND: C7.2, C8.2, C49.2, IC1.9 (GND2), IC1.15 (GND2), IC11.4 (GND1), TP2.TP; also elsewhere on the board
GNDIO: C5.2, C6.2, C47.2, C48.2, C50.2, IC1.2 (GND1), IC1.8 (GND1), IC11.5 (GND2), IC12.3 (ADR1), IC12.4 (ADR0), IC12.5 (ADIN), IC12.6 (GND), J1.A1/B12 (GND), J1.B1/A12 (GND), R11.1, R12.1, R13.1, TP1.TP, U1.2; also elsewhere on the board
unnamed: C5.1, IC1.3 (VDD1), IC1.4 (PDEN), IC1.5 (SPU)
unnamed: R10.1, U1.6
unnamed: R9.1, U1.4
unnamed: IC1.7 (UD+), R9.2
unnamed: C47.1, F1.1, IC12.1 (VDD), IC12.2 (INTVCC), IC12.12 (SENSE+), R32.1
unnamed: J1.A7 (DN), J1.B7 (DN), U1.1
unnamed: J1.A6 (DP), J1.B6 (DP), U1.3
unnamed: J1.A5 (CC1), R12.2
unnamed: J1.B5 (CC2), R11.2
unnamed: J1.P1 (SHLD), J1.P2 (SHLD), J1.P3 (SHLD), J1.P4 (SHLD), J1.S1 (SHLD), J1.S2 (SHLD), J1.S3 (SHLD), J1.S4 (SHLD), J1.S5 (SHLD), J1.S6 (SHLD), J1.S7 (SHLD), J1.S8 (SHLD), R13.2
unnamed: IC1.6 (UD-), R10.2
SCL: IC11.3 (SCL1); also elsewhere on the board
SCL_ISO: IC11.6 (SCL2), IC12.7 (SCL), R31.1
SDA: IC11.2 (SDA1); also elsewhere on the board
SDA_ISO: IC11.7 (SDA2), IC12.8 (SDAI), IC12.9 (SDAO), R30.1
USB_DM: IC1.11 (DD-); also elsewhere on the board
USB_DP: IC1.10 (DD+); also elsewhere on the board
VBUS: C6.1, C50.1, IC1.1 (VBUS1), IC11.8 (VCC2), IC12.11 (SENSE-), R30.2, R31.2, R32.2; also elsewhere on the board
VBUS_IN: C48.1, F1.2, J1.A4/B9 (VBUS), J1.B4/A9 (VBUS), U1.5

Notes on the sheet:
Copyright (c) 2021 - 2023 Bonn-Rhein-Sieg University of Applied Sciences Licensed under the terms of CC BY-SA

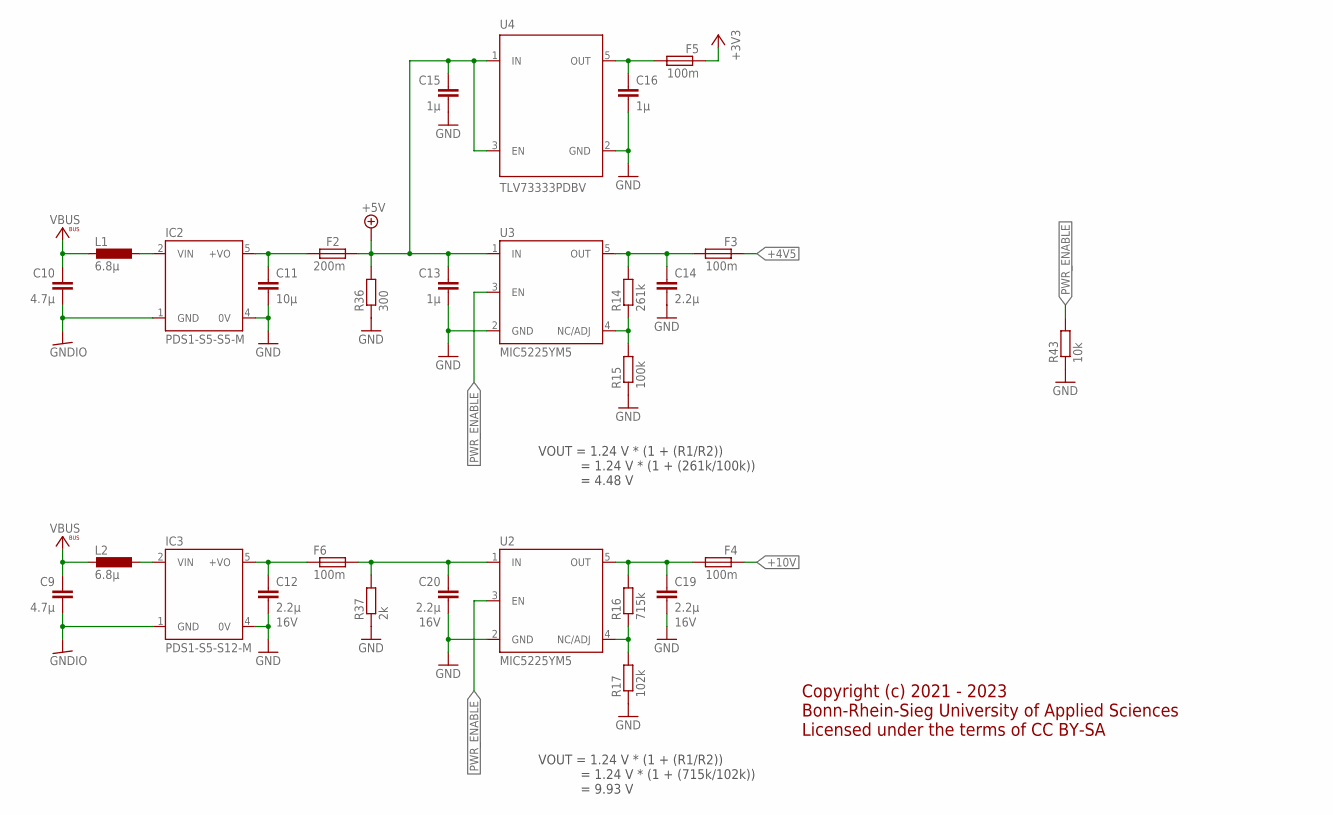
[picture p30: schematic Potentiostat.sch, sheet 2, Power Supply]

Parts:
C9, C10: 4.7µ; C0603
C11: 10µ; C0603
C12, C19, C20: 2.2µ; C0603; RATING 16V
C13, C15, C16: 1µ; C0603
C14: 2.2µ; C0603
F2: 200m; R0603
F3, F4, F5, F6: 100m; R0603
IC2: PDS1-S5-S5-M; PDS1-M
IC3: PDS1-S5-S12-M; PDS1-M
L1, L2: 6.8µ; L0603
R14: 261k; R0603
R15: 100k; R0603
R16: 715k; R0603
R17: 102k; R0603
R36: 300; R0805
R37: 2k; R0805
R43: 10k; R0603
U2, U3: MIC5225YM5; SOT23-5L
U4: TLV73333PDBV; SOT-23

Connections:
+3V3: F5.1; also elsewhere on the board
+4V5: F3.1; also elsewhere on the board
+5V: C13.1, C15.1, F2.2, R36.2, U3.1 (IN), U4.1 (IN), U4.3 (EN)
+10V: F4.1; also elsewhere on the board
GND: C11.2, C12.2, C13.2, C14.2, C15.2, C16.2, C19.2, C20.2, IC2.4 (0V), IC3.4 (0V), R15.1, R17.1, R36.1, R37.1, R43.1, U2.2 (GND), U3.2 (GND), U4.2 (GND); also elsewhere on the board
GNDIO: C9.2, C10.2, IC2.1 (GND), IC3.1 (GND); also elsewhere on the board
unnamed: R14.1, R15.2, U3.4 (NC/ADJ)
unnamed: C20.1, F6.2, R37.2, U2.1 (IN)
unnamed: R16.1, R17.2, U2.4 (NC/ADJ)
unnamed: C12.1, F6.1, IC3.5 (+VO)
unnamed: C16.1, F5.2, U4.5 (OUT)
unnamed: C14.1, F3.2, R14.2, U3.5 (OUT)
unnamed: C19.1, F4.2, R16.2, U2.5 (OUT)
unnamed: IC2.2 (VIN), L1.1
unnamed: IC3.2 (VIN), L2.1
unnamed: C11.1, F2.1, IC2.5 (+VO)
PWR_ENABLE: R43.2, U2.3 (EN), U3.3 (EN); also elsewhere on the board
VBUS: C9.1, C10.1, L1.2, L2.2; also elsewhere on the board

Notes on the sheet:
VOUT = 1.24 V * (1 + (R1/R2)) = 1.24 V * (1 + (261k/100k)) = 4.48 V
VOUT = 1.24 V * (1 + (R1/R2)) = 1.24 V * (1 + (715k/102k)) = 9.93 V
Copyright (c) 2021 - 2023 Bonn-Rhein-Sieg University of Applied Sciences Licensed under the terms of CC BY-SA

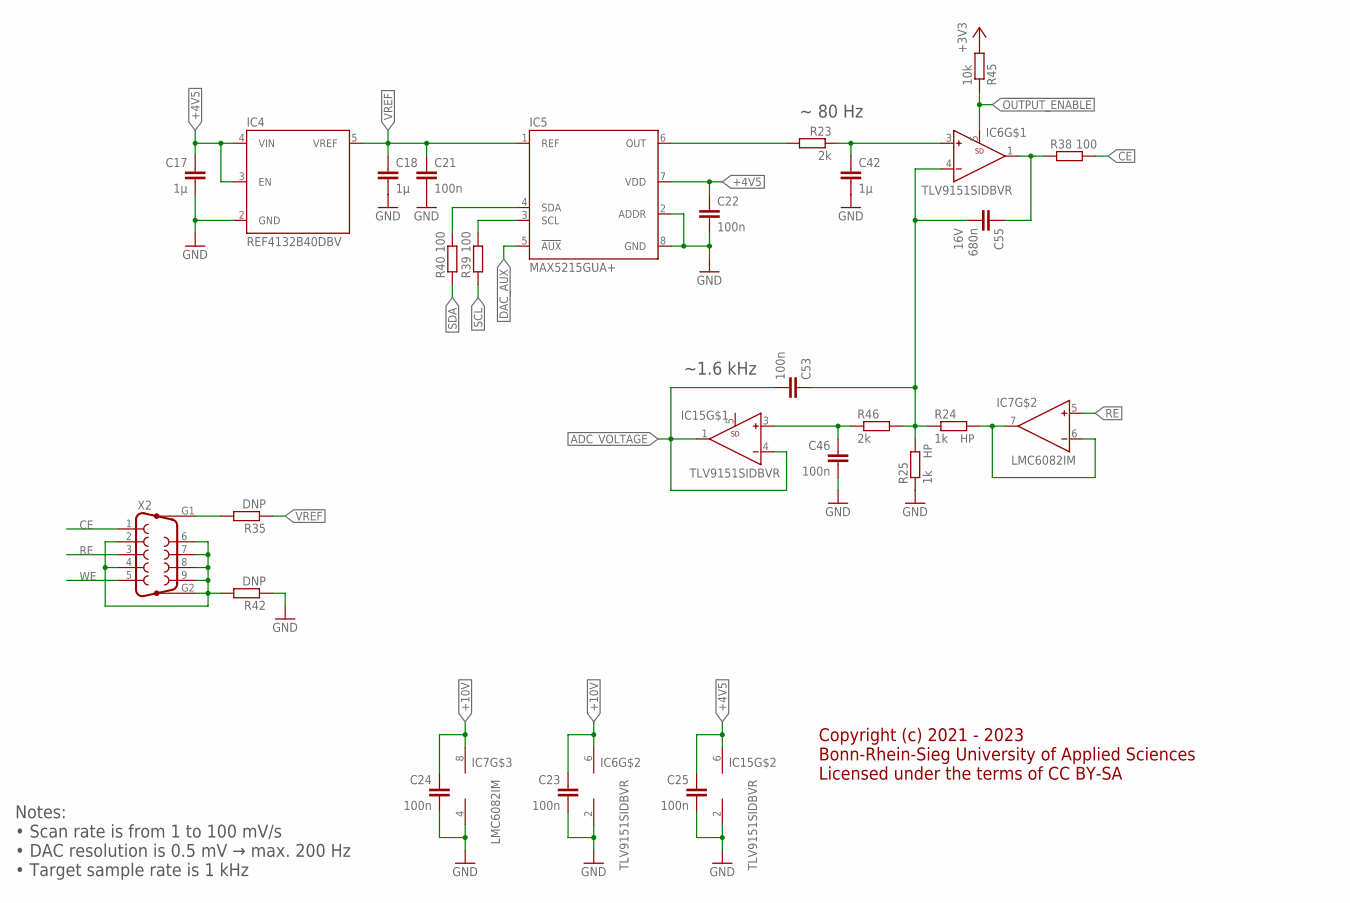
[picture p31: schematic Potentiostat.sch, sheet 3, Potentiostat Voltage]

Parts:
C17, C18, C42: 1µ; C0603
C21, C22, C23, C24, C25, C46, C53: 100n; C0603
C55: 680n; C0603; RATING 16V
IC4: REF4132B40DBV; SOT23-5
IC5: MAX5215GUA+; MSOP8
IC6, IC15: TLV9151SIDBVR; SOT23-6
IC7: LMC6082IM; SOIC8
R23, R46: 2k; R0603
R24, R25: 1k; R0603
R35, R42: DNP; R0603
R38, R39, R40: 100; R0603
R45: 10k; R0603
X2: A-DF_09

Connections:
!OUTPUT_ENABLE: IC6.5 (SD), R45.1; also elsewhere on the board
+3V3: R45.2; also elsewhere on the board
+4V5: C17.1, C22.1, C25.1, IC4.3 (EN), IC4.4 (VIN), IC5.7 (VDD), IC15.6 (V+); also elsewhere on the board
+10V: C23.1, C24.1, IC6.6 (V+), IC7.8 (V+); also elsewhere on the board
ADC_VOLTAGE: C53.2, IC15.1 (OUT), IC15.4 (IN-); also elsewhere on the board
CE: R38.2, X2.1
DAC_AUX: IC5.5 (!AUX); also elsewhere on the board
GND: C17.2, C18.2, C21.2, C22.2, C23.2, C24.2, C25.2, C42.2, C46.2, IC4.2 (GND), IC5.2 (ADDR), IC5.8 (GND), IC6.2 (V-), IC7.4 (V-), IC15.2 (V-), R25.1, R42.1; also elsewhere on the board
unnamed: IC5.6 (OUT), R23.2
unnamed: IC7.6 (IN-), IC7.7 (OUT), R24.2
unnamed: C53.1, C55.2, IC6.4 (IN-), R24.1, R25.2, R46.2
unnamed: C42.1, IC6.3 (IN+), R23.1
unnamed: C55.1, IC6.1 (OUT), R38.1
unnamed: IC5.3 (SCL), R39.2
unnamed: R42.2, X2.2, X2.4, X2.6, X2.7, X2.8, X2.9, X2.G2
unnamed: R35.2, X2.G1
unnamed: IC5.4 (SDA), R40.2
unnamed: C46.1, IC15.3 (IN+), R46.1
RE: IC7.5 (IN+), X2.3
SCL: R39.1; also elsewhere on the board
SDA: R40.1; also elsewhere on the board
VREF: C18.1, C21.1, IC4.5 (VREF), IC5.1 (REF), R35.1; also elsewhere on the board
WE: X2.5; also elsewhere on the board

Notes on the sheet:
~ 80 Hz
Notes: • Scan rate is from 1 to 100 mV/s • DAC resolution is 0.5 mV → max. 200 Hz • Target sample rate is 1 kHz
~1.6 kHz
Copyright (c) 2021 - 2023 Bonn-Rhein-Sieg University of Applied Sciences Licensed under the terms of CC BY-SA


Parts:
C1: 2.2µ; C0603; RATING 16V
C2: 33n; C0603
C3: 330p; C0603
C4: 100p; C0603
C43, C44, C45, C51, C52, C54: 100n; C0603
IC7: LMC6082IM; SOIC8
IC9: ADG659YRQZ; QSOP16
IC13, IC14: TLV9151SIDBVR; SOT23-6
R2: 10k; R0603
R3, R4: 1k; R0603
R5, R8: 10M; R0805
R6, R7: 2M; R0805
R26, R27: 20k; R0805
R28, R29: 200; R0805
R47: 2k; R0603

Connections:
!MUX_EN: IC9.6 (!EN), R2.1; also elsewhere on the board
+3V3: R2.2; also elsewhere on the board
+4V5: C52.1, IC13.6 (V+); also elsewhere on the board
+10V: C43.1, C51.1, IC9.16 (VDD), IC14.6 (V+); also elsewhere on the board
ADC_CURRENT: C54.2, IC13.1 (OUT), IC13.4 (IN-); also elsewhere on the board
GND: C43.2, C44.2, C45.2, C51.2, C52.2, IC9.7 (VSS), IC9.8 (GND), IC13.2 (V-), IC14.2 (V-), R4.1; also elsewhere on the board
MUX_A0: IC9.10 (A0); also elsewhere on the board
MUX_A1: IC9.9 (A1); also elsewhere on the board
MUX_GAIN1: C4.2, IC9.1 (S1B), IC9.12 (S1A), R5.2
MUX_GAIN2: C3.2, IC9.5 (S2B), IC9.14 (S2A), R7.2
MUX_GAIN3: C2.2, IC9.2 (S3B), IC9.15 (S3A), R27.2
MUX_GAIN4: C1.2, IC9.4 (S4B), IC9.11 (S4A), R29.2
MUX_IN: IC7.1 (OUT), IC9.13 (DA)
MUX_OUT: IC9.3 (DB), IC14.3 (IN+)
unnamed: C45.1, IC13.3 (IN+), R47.1
unnamed: R5.1, R8.2
unnamed: R6.2, R7.1
unnamed: R26.2, R27.1
unnamed: R28.2, R29.1
unnamed: IC14.1 (OUT), IC14.4 (IN-), R3.1
unnamed: C54.1, R3.2, R4.2, R47.2
VREF: C44.1, IC7.3 (IN+); also elsewhere on the board
WE: C1.1, C2.1, C3.1, C4.1, IC7.2 (IN-), R6.1, R8.1, R26.1, R28.1; also elsewhere on the board

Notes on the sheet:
Kelvin-Switching
~1.6 kHz
Copyright (c) 2021 - 2023 Bonn-Rhein-Sieg University of Applied Sciences Licensed under the terms of CC BY-SA

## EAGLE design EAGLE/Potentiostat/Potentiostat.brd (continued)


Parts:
C26, C27: 100n; C0603
C28, C29, C31, C32, C35, C36: 1µ; C0603
C30, C34: 47µ; C0805
C33, C37: 10n; C0603
L3: BLM18HE152SN1D; 0603
R1, R44: 10k; R0603
R18, R19, R20, R21: 10; R0603
U5, U6: ADS8866IDGS; MSOP10
U7, U8: REF6141IDGK; VSSOP8

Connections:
+3V3: C32.1, C36.1, L3.2, R1.2, R44.2, U5.10 (DVDD), U6.10 (DVDD); also elsewhere on the board
+3V3A: C31.1, C35.1, L3.1, U5.2 (AVDD), U6.2 (AVDD)
+4V5: C26.1, C27.1, U7.1 (VIN), U7.2 (EN), U7.3 (SS), U8.1 (VIN), U8.2 (EN), U8.3 (SS); also elsewhere on the board
ADC_CONVST: U5.6 (CONVST), U6.6 (CONVST); also elsewhere on the board
ADC_CS1: R1.1, U5.9 (DIN); also elsewhere on the board
ADC_CS2: R44.1, U6.9 (DIN); also elsewhere on the board
ADC_CURRENT: R20.1; also elsewhere on the board
ADC_MISO: U5.7 (DOUT), U6.7 (DOUT); also elsewhere on the board
ADC_SCK: U5.8 (SCLK), U6.8 (SCLK); also elsewhere on the board
ADC_VOLTAGE: R18.1; also elsewhere on the board
GND: C26.2, C27.2, C28.2, C29.2, C30.2, C31.2, C32.2, C34.2, C35.2, C36.2, R19.1, R21.1, U5.5 (GND), U6.5 (GND), U7.7 (GND_F), U7.8 (GND_S), U8.7 (GND_F), U8.8 (GND_S); also elsewhere on the board
unnamed: C28.1, U7.4 (FILT)
unnamed: C30.1, U5.1 (REF), U7.5 (OUT_S), U7.6 (OUT_F)
unnamed: C33.1, R18.2, U5.3 (AINP)
unnamed: C29.1, U8.4 (FILT)
unnamed: C34.1, U6.1 (REF), U8.5 (OUT_S), U8.6 (OUT_F)
unnamed: C33.2, R19.2, U5.4 (AINN)
unnamed: C37.1, R20.2, U6.3 (AINP)
unnamed: C37.2, R21.2, U6.4 (AINN)

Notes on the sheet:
R must be ≤ 22 Ω
Copyright (c) 2021 - 2023 Bonn-Rhein-Sieg University of Applied Sciences Licensed under the terms of CC BY-SA


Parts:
C38, C39: 100n; C0603
C40: 10n; C0603
C41: 1µ; C0603
IC10: STM32L412KBT6; LQFP32
J2: 6210XX21021_62101021021; 62101021021
LED3: DUAL0805; CHIPLEDX2
Q1: FOX924B-16.000; FOX924B
R22: 10k; R0603
R33, R34: 4.7k; R0603
R41: 200; R0603

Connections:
!MUX_EN: IC10.28 (PB5); also elsewhere on the board
!NRST: IC10.4 (!NRST), J2.10
!OUTPUT_ENABLE: IC10.18 (PA8); also elsewhere on the board
+3V3: C38.1, C39.1, C40.1, C41.1, IC10.1 (VDD), IC10.5 (VDDA/VREF+), IC10.17 (VDD), J2.1, Q1.4 (VCC), R33.2, R34.2, R41.1; also elsewhere on the board
ADC_CONVST: IC10.8 (PA2); also elsewhere on the board
ADC_CS1: IC10.9 (PA3); also elsewhere on the board
ADC_CS2: IC10.10 (PA4); also elsewhere on the board
ADC_MISO: IC10.12 (PA6); also elsewhere on the board
ADC_SCK: IC10.11 (PA5); also elsewhere on the board
CLOCK: IC10.6 (PA0-CK_IN), Q1.3 (OUT)
DAC_AUX: IC10.13 (PA7); also elsewhere on the board
GND: C38.2, C39.2, C40.2, C41.2, IC10.16 (VSS), IC10.32 (VSS), J2.3, J2.5, Q1.2 (GND), R22.1; also elsewhere on the board
MUX_A0: IC10.26 (PB3); also elsewhere on the board
MUX_A1: IC10.27 (PB4); also elsewhere on the board
unnamed: IC10.31 (BOOT0-PH3), R22.2
unnamed: LED3.A1 (A), LED3.A2 (A), R41.2
PWR_ENABLE: IC10.2 (PC14-OSC32_IN); also elsewhere on the board
SCL: IC10.29 (PB6), R34.1; also elsewhere on the board
SDA: IC10.30 (PB7), R33.1; also elsewhere on the board
STATUS_BAD: IC10.15 (PB1), LED3.C1 (C)
STATUS_GOOD: IC10.14 (PB0), LED3.C2 (C)
SWCLK: IC10.24 (PA14), J2.4
SWDIO: IC10.23 (PA13), J2.2
USB_DM: IC10.21 (PA11); also elsewhere on the board
USB_DP: IC10.22 (PA12); also elsewhere on the board

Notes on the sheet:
Copyright (c) 2021 - 2023 Bonn-Rhein-Sieg University of Applied Sciences Licensed under the terms of CC BY-SA


Board: 2 copper layers, 70.0 x 90.0 mm, 144 parts (0 on the bottom side), 92 nets.

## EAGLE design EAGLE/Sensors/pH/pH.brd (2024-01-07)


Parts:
C1, C2: 2.2µ; C0603
C3, C7, C8, C9: 100n; C0603
C4, C5, C6: 1µ; C0603
H1, H2, H3, H4: MOUNTHOLE-2.0; 2.0
IC1: LMP91200MT; TSSOP16
IC2: REF4132B40DBV; SOT23-5
R1: 10.5k; R0603
R2: 100k; R0603
U1: AP7311-WG; SOT-23
U2: ADS1110A0IDBV; SOT23-6
X1: SFM-105-02-L-D; SAMTEC-SFM-105-02-L-D
X2: 031-5329-51RFX

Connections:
+5V: C1.1, C5.1, C7.1, IC2.3 (EN), IC2.4 (VIN), U1.1 (IN), U1.3 (EN), X1.1, X1.2
GND: C1.2, C2.2, C3.2, C4.2, C5.2, C6.2, C7.2, C8.2, C9.2, IC1.10 (GND), IC1.13 (GND), IC1.15 (GND), IC1.16 (GND), IC2.2 (GND), R1.1, U1.2 (GND), U2.2 (GND), X1.3, X1.4, X1.10
ID_0: X1.8
INP: IC1.5 (INP), X2.1
unnamed: IC1.4 (GUARD1), IC1.6 (GUARD2)
unnamed: R1.2, R2.1, U1.4 (ADJ)
SCL: U2.3 (SCL), X1.9
SDA: U2.4 (SDA), X1.7
VCC: C2.1, C3.1, C4.1, C9.1, IC1.1 (VDD), IC1.14 (VDD), R2.2, U1.5 (OUT), U2.5 (VDD), X1.5, X1.6
VCM: IC1.8 (VCM), X2.2, X2.3 (2), X2.4 (2), X2.5 (2)
VOCM: IC1.11 (VOCM), U2.6 (VIN-)
VOUT: IC1.12 (VOUT), U2.1 (VIN+)
VREF: C6.1, C8.1, IC1.9 (VREF), IC2.5 (VREF)

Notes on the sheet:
0.4 V (1 + 100 kΩ / 10.5 kΩ) ≈ 4.21 V
Sensor ID: 01
Copyright (c) 2021 - 2023 Bonn-Rhein-Sieg University of Applied Sciences Licensed under the terms of CC BY-SA


Board: 2 copper layers, 30.0 x 30.0 mm, 21 parts (1 on the bottom side), 12 nets.

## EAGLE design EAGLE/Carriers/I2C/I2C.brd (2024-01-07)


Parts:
C1: 2.2µ; C0805
C4: 1µ; C0805
C5: 10µ; C0603
C6: 10n; C0603
C7, C9, C10: 100n; C0603
C13: 1µ; C0603
F1: 500m; R0603
H1, H2, H3, H4: MOUNTHOLE-2.0; 2.0
IC1: ZXCT1110QW5-7; SOT23-5L
IC2: STM32L412KBT6; LQFP32
J2: 2171790001; 2171790001_MOL
J3: 6210XX21021_62101021021; 62101021021
LED1: DUAL0805; CHIPLEDX2
R3, R4: 5.1k; R0603
R11, R21, R22: 10k; R0603
R12, R13: 200; R0603
R14: 1M; R0603
R19: 180m; R0805
R20: 7.87k; R0603
R35, R36: 0; R0603
TP3: TP3.8X2.03; 3.8X2.03
U2: LP2985IM5-3.3; SOT23-5
U3: USBLC6-2P6; SOT-666

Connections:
!NRST: IC2.4 (!NRST), J3.10
BUS_CURRENT: IC1.3 (OUT), IC2.7 (PA1), R20.2
BUS_VOLTAGE: IC2.6 (PA0-CK_IN), R21.2, R22.1
BUS_VOLTAGE_AMPLIFIED: IC2.9 (PA3)
GND: C1.2, C4.2, C5.2, C6.2, C7.2, C9.2, C10.2, C13.2, IC1.2 (GND), IC2.16 (VSS), IC2.32 (VSS), J2.A1/B12 (GND), J2.B1/A12 (GND), J3.3, J3.5, R3.1, R4.1, R11.1, R14.1, R20.1, R22.2, R35.1, R36.1, TP3.TP, U2.2 (GND), U3.2; also elsewhere on the board
ID1_0: IC2.10 (PA4); also elsewhere on the board
ID1_1: IC2.11 (PA5); also elsewhere on the board
ID2_0: IC2.2 (PC14-OSC32_IN); also elsewhere on the board
ID2_1: IC2.3 (PC15-OSC32_OUT); also elsewhere on the board
unnamed: J2.P1 (SHLD), J2.P2 (SHLD), J2.P3 (SHLD), J2.P4 (SHLD), J2.S1 (SHLD), J2.S2 (SHLD), J2.S3 (SHLD), J2.S4 (SHLD), J2.S5 (SHLD), J2.S6 (SHLD), J2.S7 (SHLD), J2.S8 (SHLD), R14.2
unnamed: J2.A6 (DP), J2.B6 (DP), U3.3
unnamed: J2.A7 (DN), J2.B7 (DN), U3.1
unnamed: J2.B5 (CC2), R3.2
unnamed: J2.A5 (CC1), R4.2
unnamed: C6.1, U2.4 (BYPASS)
unnamed: IC2.31 (BOOT0-PH3), R11.2
unnamed: LED1.A2 (A), R13.1
unnamed: LED1.A1 (A), R12.1
unnamed: F1.2, IC1.4 (S+), R19.1
SCL1: IC2.13 (PA7); also elsewhere on the board
SCL2: IC2.29 (PB6); also elsewhere on the board
SDA1: IC2.27 (PB4); also elsewhere on the board
SDA2: IC2.30 (PB7); also elsewhere on the board
STATUS_BAD: IC2.26 (PB3), LED1.C1 (C)
STATUS_GOOD: IC2.25 (PA15), LED1.C2 (C)
SWCLK: IC2.24 (PA14), J3.4
SWDIO: IC2.23 (PA13), J3.2
USB_DM: IC2.21 (PA11), U3.6
USB_DP: IC2.22 (PA12), U3.4
VARIANT0: IC2.14 (PB0), R36.2
VARIANT1: IC2.15 (PB1), R35.2
VBUS: C1.1, C4.1, IC1.5 (S-), R19.2, R21.1, U2.1 (IN), U2.3 (ON/OFF); also elsewhere on the board
VBUS_IN: F1.1, J2.A4/B9 (VBUS), J2.B4/A9 (VBUS), U3.5
VCC: C5.1, C7.1, C9.1, C10.1, C13.1, IC2.1 (VDD), IC2.5 (VDDA/VREF+), IC2.17 (VDD), J3.1, R12.2, R13.2, U2.5 (OUT); also elsewhere on the board

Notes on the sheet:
100 mV / 500 mA = 200 mΩ
7.87 kΩ * 0.004 * 100 mV = 3.148 V
Copyright (c) 2021 - 2023 Bonn-Rhein-Sieg University of Applied Sciences Licensed under the terms of CC BY-SA


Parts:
C2, C3, C8, C12: 100n; C0603
C11: 2.2µ; C0603
C27: 10µ; C0603
CON1: TFM-105-02-L-D; SAMTEC_TFM-105-02-L-D
F2: 50m; R0603
H5, H6, H7: MOUNTHOLE-2.0; 2.0
OK1: ILD205; SOIC08
R1, R2: 100; R0603
R5: 30.9k; R0603
R6, R15, R16: 10k; R0603
R7, R8, R9, R10: 4.7k; R0603
R17, R18: 49.9k; R0603
TP1: TP3.8X2.03; 3.8X2.03
U1: ADM3260ARSZ; SSOP20

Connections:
GND: C3.1, C11.1, C12.1, OK1.5 (EMIT), OK1.7 (EMIT), U1.1 (GNDP), U1.5 (GNDP), U1.7 (GNDP), U1.8 (PDIS), U1.10 (GNDP); also elsewhere on the board
GNDISO1: C2.1, C8.1, C27.1, CON1.03, CON1.04, R6.1, TP1.TP, U1.11 (GNDISO), U1.14 (GNDISO), U1.16 (GNDISO), U1.20 (GNDISO)
ID1_0: OK1.8 (COL), R17.1; also elsewhere on the board
ID1_0_ISO: CON1.08, OK1.2 (C)
ID1_1: OK1.6 (COL), R18.1; also elsewhere on the board
ID1_1_ISO: CON1.10, OK1.4 (C)
unnamed: CON1.09, R1.2
unnamed: R5.1, R6.2, U1.13 (VSEL)
unnamed: CON1.07, R2.2
unnamed: OK1.3 (A), R16.1
unnamed: OK1.1 (A), R15.1
unnamed: C8.2, C27.2, F2.2, U1.12 (VISO)
SCL1: R9.1, U1.2 (SCL2); also elsewhere on the board
SCL1_ISO: R1.1, R8.1, U1.19 (SCL1)
SDA1: R10.1, U1.3 (SDA2); also elsewhere on the board
SDA1_ISO: R2.1, R7.1, U1.18 (SDA1)
VBUS: C11.2, C12.2, U1.9 (VIN); also elsewhere on the board
VCC: C3.2, R9.2, R10.2, R17.2, R18.2, U1.4 (VDDP); also elsewhere on the board
VDDISO1: C2.2, CON1.05, CON1.06, R7.2, R8.2, U1.17 (VDDISO)
VISO1: CON1.01, CON1.02, F2.1, R5.2, R15.2, R16.2

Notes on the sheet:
~0.4 mA input current is sufficient to generate a low level at the output
Copyright (c) 2021 - 2023 Bonn-Rhein-Sieg University of Applied Sciences Licensed under the terms of CC BY-SA


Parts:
C14, C17, C18, C19: 100n; C0603
C15: 10µ; C0603
C16: 2.2µ; C0603
CON2: TFM-105-02-L-D; SAMTEC_TFM-105-02-L-D
F3: 50m; R0603
H8, H9, H10: MOUNTHOLE-2.0; 2.0
OK2: ILD205; SOIC08
R23, R24: 100; R0603
R25: 30.9k; R0603
R26, R31, R32: 10k; R0603
R27, R28, R29, R30: 4.7k; R0603
R33, R34: 49.9k; R0603
TP2: TP3.8X2.03; 3.8X2.03
U4: ADM3260ARSZ; SSOP20

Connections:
GND: C16.1, C17.1, C19.1, OK2.5 (EMIT), OK2.7 (EMIT), U4.1 (GNDP), U4.5 (GNDP), U4.7 (GNDP), U4.8 (PDIS), U4.10 (GNDP); also elsewhere on the board
GNDISO2: C14.1, C15.1, C18.1, CON2.03, CON2.04, R26.1, TP2.TP, U4.11 (GNDISO), U4.14 (GNDISO), U4.16 (GNDISO), U4.20 (GNDISO)
ID2_0: OK2.8 (COL), R33.1; also elsewhere on the board
ID2_0_ISO: CON2.08, OK2.2 (C)
ID2_1: OK2.6 (COL), R34.1; also elsewhere on the board
ID2_1_ISO: CON2.10, OK2.4 (C)
unnamed: R25.1, R26.2, U4.13 (VSEL)
unnamed: CON2.09, R23.2
unnamed: CON2.07, R24.2
unnamed: OK2.3 (A), R32.1
unnamed: OK2.1 (A), R31.1
unnamed: C14.2, C15.2, F3.2, U4.12 (VISO)
SCL2: R29.1, U4.2 (SCL2); also elsewhere on the board
SCL2_ISO: R23.1, R28.1, U4.19 (SCL1)
SDA2: R30.1, U4.3 (SDA2); also elsewhere on the board
SDA2_ISO: R24.1, R27.1, U4.18 (SDA1)
VBUS: C16.2, C17.2, U4.9 (VIN); also elsewhere on the board
VCC: C19.2, R29.2, R30.2, R33.2, R34.2, U4.4 (VDDP); also elsewhere on the board
VDDISO2: C18.2, CON2.05, CON2.06, R27.2, R28.2, U4.17 (VDDISO)
VISO2: CON2.01, CON2.02, F3.1, R25.2, R31.2, R32.2

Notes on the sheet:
~0.4 mA input current is sufficient to generate a low level at the output
Copyright (c) 2021 - 2023 Bonn-Rhein-Sieg University of Applied Sciences Licensed under the terms of CC BY-SA


Board: 2 copper layers, 62.0 x 60.0 mm, 85 parts (0 on the bottom side), 59 nets.

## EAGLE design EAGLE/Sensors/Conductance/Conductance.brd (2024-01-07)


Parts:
C1: 470n; C0603
C3: 1µ; C0603
C7, C8, C9, C10, C11: 100n; C0603
H1, H2, H3, H4: MOUNTHOLE-2.0; 2.0
IC1: STM32L552RCT6; LQFP64
IC2: REF3130; SOT23
J3: 6210XX21021_62101021021; 62101021021
LED_: DUAL0805; CHIPLEDX2
Q1: FOX924B-16.000; FOX924B
R18, R19: 806; R0603
R29: 10k; R0603
U$1: SFM-107-02-L-D; SAMTEC-SFM-107-02-L-D

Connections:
!NRST: IC1.7 (NRST), J3.10
BOOT0: IC1.60 (BOOT0/PH3), R29.2
CIN_FILTERED: IC1.16 (PA2); also elsewhere on the board
COMM_CON: IC1.37 (PC6), U$1.2
COMM_CS: IC1.33 (PB12), U$1.14
COMM_DRDY: IC1.34 (PB13), U$1.1
COMM_MISO: IC1.35 (PB14), U$1.12
COMM_MOSI: IC1.36 (PB15), U$1.11
COMM_SCK: IC1.29 (PB10), U$1.13
DAC_OUT: IC1.21 (PA5); also elsewhere on the board
GND: C1.2, C3.2, C7.2, C8.2, C9.2, C10.2, C11.2, IC1.12 (VSSA/VREF-), IC1.18 (VSS), IC1.31 (VSS), IC1.47 (VSS), IC1.50 (PA15), IC1.63 (VSS), IC2.3 (GND), J3.3, J3.5, Q1.2 (GND), R29.1, U$1.7, U$1.8, U$1.9, U$1.10; also elsewhere on the board
MUX_A0: IC1.55 (PB3); also elsewhere on the board
MUX_A1: IC1.56 (PB4); also elsewhere on the board
MUX_EN: IC1.54 (PD2); also elsewhere on the board
unnamed: LED_.A1 (A), R18.1
unnamed: LED_.A2 (A), R19.1
OSC_IN: IC1.5 (PH0/OSC_IN), Q1.3 (OUT)
STATUS_BAD: IC1.53 (PC12), LED_.C1 (C)
STATUS_GOOD: IC1.52 (PC11), LED_.C2 (C)
SWCLK: IC1.49 (SWCLK/PA14), J3.4
SWDIO: IC1.46 (SWDIO/PA13), J3.2
VCC: C1.1, C8.1, C9.1, C10.1, C11.1, IC1.1 (VBAT), IC1.19 (VDD), IC1.32 (VDD), IC1.48 (VDDUSB), IC1.51 (PC10), IC1.64 (VDD), IC2.1 (IN), J3.1, Q1.4 (VCC), R18.2, R19.2, U$1.3, U$1.4, U$1.5, U$1.6; also elsewhere on the board
VOUT: IC1.22 (PA6); also elsewhere on the board
VOUT_BUFFERED: IC1.26 (PB0); also elsewhere on the board
VOUT_FILTERED: IC1.24 (PC4); also elsewhere on the board
VREF: C3.1, C7.1, IC1.13 (VDDA/VREF+), IC2.2 (OUT); also elsewhere on the board
VZERO: IC1.20 (PA4); also elsewhere on the board

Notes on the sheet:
2.0
VERSION
Copyright (c) 2021 - 2023 Bonn-Rhein-Sieg University of Applied Sciences Licensed under the terms of CC BY-SA


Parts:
C2, C5: 1n; C0603
C4: 100p; C0603
C12, C15, C16, C17, C22: 100n; C0603
IC3: ADG804YRMZ; MSOP10
IC4, IC5: MCP6V91U-E/OT; SOT23-5
R1, R6, R12, R14: 100k; R0603
R2, R7, R8, R11: 100; R0603
R3, R9, R10, R13: 1M; R0603
R4: 1k; R0603
R5: 10k; R0603
X1: AKL055-2

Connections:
CIN: C4.2, IC3.8 (D), IC5.4 (OUT), R11.1
CIN_FILTERED: C16.1, R11.2; also elsewhere on the board
DAC_OUT: R3.2, R13.1, R14.1; also elsewhere on the board
GND: C2.2, C12.1, C15.2, C16.2, C17.1, C22.1, IC3.3 (GND), IC4.2 (VSS), IC5.2 (VSS), R10.2, R12.1, R13.2; also elsewhere on the board
MUX_A0: IC3.1 (A0); also elsewhere on the board
MUX_A1: IC3.10 (A1); also elsewhere on the board
MUX_EN: IC3.5 (EN), R12.2; also elsewhere on the board
MUX_S1: IC3.2 (S1), R2.2
MUX_S2: IC3.9 (S2), R4.2
MUX_S3: IC3.4 (S3), R5.2
MUX_S4: IC3.7 (S4), R6.2
unnamed: C5.2, R1.1, R14.2
unnamed: C2.1, IC4.1 (IN+), R1.2
unnamed: C5.1, IC4.3 (IN-), IC4.4 (OUT), R7.2
VCC: C12.2, C17.2, C22.2, IC3.6 (VDD), IC4.5 (VDD), IC5.5 (VDD); also elsewhere on the board
VIN: C4.1, IC5.3 (IN-), R2.1, R4.1, R5.1, R6.1, X1.1
VOUT: R7.1, X1.2 (4); also elsewhere on the board
VOUT_BUFFERED: R8.1; also elsewhere on the board
VOUT_FILTERED: C15.1, R8.2; also elsewhere on the board
VREF: R3.1, R9.1; also elsewhere on the board
VZERO: IC5.1 (IN+), R9.2, R10.1; also elsewhere on the board

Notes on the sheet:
Note: DAC has very low capacitive load capabilities, use high resistance and low capacitance for reconstruction filter.
Note: When the µController is uninitialized, DAC outputs are high-impedance. Hold the signals at VZERO to make sure there is no voltage difference across the electrodes between VOUT and VIN.
2.0
Changelog: * Drive VZERO using DAC * Use second-order reconstruction filter
~ 1.6 kHz
~ 16 kHz
Copyright (c) 2021 - 2023 Bonn-Rhein-Sieg University of Applied Sciences Licensed under the terms of CC BY-SA


Board: 2 copper layers, 40.0 x 40.0 mm, 46 parts (1 on the bottom side), 36 nets.

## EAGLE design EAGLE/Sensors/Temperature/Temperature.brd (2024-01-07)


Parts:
C1, C2, C7: 100n; C0603
C3, C6: 10n; C0603
C4: 1µ; C0603
C5: 10µ; C0603
H1, H2, H3, H4: MOUNTHOLE-2.0; 2.0
IC1: SC18IS602B; TSSOP16
IC2: MAX31865AAP+; SSOP20
JP1, JP2: JP1E; JP1
R1: 4.02k; R0603
R2: 10M; R0603
R7: 100; R0603
RN1: 270; EXB38V
U2: LP2985IM5-3.3; SOT23-5
X1: SFM-105-02-L-D; SAMTEC-SFM-105-02-L-D
X2: OSTTE040104; OSTTE04

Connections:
+5V: C4.1, U2.1 (IN), U2.3 (ON/OFF), X1.1, X1.2
BIAS: IC2.4 (BIAS), IC2.5 (REFIN+), R1.2, R2.2
FORCE+: IC2.8 (FORCE+), JP1.1, X2.1
FORCE-: IC2.12 (FORCE-), JP2.2, X2.4
GND: C1.2, C2.2, C4.2, C5.2, C6.2, C7.2, IC1.4 (VSS), IC1.14 (A0), IC1.15 (A1), IC1.16 (A2), IC2.9 (FORCE2), IC2.13 (GND), IC2.18 (DGND), IC2.19 (GND), U2.2 (GND), X1.3, X1.4, X1.8
ID_1: X1.10
unnamed: IC1.10 (!SS2), R7.2
unnamed: IC2.16 (!CS), RN1.6 (2)
unnamed: IC2.15 (SCLK), RN1.7 (2)
unnamed: IC2.6 (REFIN-), IC2.7 (ISENSOR), R1.1
unnamed: IC2.17 (SDO), RN1.5 (2)
unnamed: IC2.14 (SDI), RN1.8 (2)
unnamed: IC1.6 (MOSI), RN1.1
unnamed: C6.1, U2.4 (BYPASS)
unnamed: IC1.5 (MISO), RN1.4 (1)
unnamed: IC1.11 (SCLK), RN1.2 (1)
unnamed: IC1.2 (!SS1), RN1.3 (1)
unnamed: IC2.1 (!DRDY), R7.1
RTDIN+: C3.1, IC2.10 (RTDIN+), JP1.2, R2.1, X2.2
RTDIN-: C3.2, IC2.11 (RTDIN-), JP2.1, X2.3
SCL: IC1.8 (SCL), X1.9
SDA: IC1.7 (SDA), X1.7
VCC: C1.1, C2.1, C5.1, C7.1, IC1.3 (!RESET), IC1.12 (VDD), IC2.2 (DVDD), IC2.3 (VDD), U2.5 (OUT), X1.5, X1.6

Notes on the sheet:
Detect disconnected cable by measuring full-scale voltage
Sensor ID: 10
Copyright (c) 2021 - 2023 Bonn-Rhein-Sieg University of Applied Sciences Licensed under the terms of CC BY-SA


Board: 2 copper layers, 30.0 x 30.0 mm, 22 parts (1 on the bottom side), 22 nets.

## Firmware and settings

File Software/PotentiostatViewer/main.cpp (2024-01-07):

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
#include "device.h"
#include "mainwindow.h"

#include <QApplication>

// ---------------------------------------------------------------------------------------------- //

auto main(int argc, char* argv[]) -> int
{
    qRegisterMetaType<DeviceListener::SampleBuffer>("DeviceListener::SampleBuffer");
    qRegisterMetaType<Device::CurrentRange>("Device::CurrentRange");
    qRegisterMetaType<Device::PowerValues>("Device::PowerValues");
    qRegisterMetaType<Device::Calibration>("Device::Calibration");
    qRegisterMetaType<DeviceCalibrator*>("DeviceCalibrator*");
    qRegisterMetaType<size_t>("size_t");

    QApplication::setOrganizationName("Bonn-Rhein-Sieg University of Applied Sciences");
    QApplication::setApplicationName("ISF Potentiostat Viewer");
    QApplication::setApplicationVersion(APPLICATION_VERSION);

    QApplication application(argc, argv);

    MainWindow window;
    window.show();

    return QApplication::exec();
}

// ---------------------------------------------------------------------------------------------- //

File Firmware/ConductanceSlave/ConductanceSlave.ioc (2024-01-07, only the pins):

Mcu.UserName=STM32L552RCTx
PA2.GPIO_Label=CIN_FILTERED
PA2.Signal=ADCx_IN7
PA4.GPIO_Label=VZERO
PA4.Signal=COMP_DAC11_group
PA5.GPIO_Label=DAC_OUT
PA5.Signal=COMP_DAC12_group
PA6.GPIO_Label=VOUT
PA6.Signal=OPAMP2_VINP
PB0.GPIO_Label=VOUT_BUFFERED
PB0.Signal=OPAMP2_VOUT
PB10.GPIO_Label=COMM_SCK
PB10.Signal=SPI2_SCK
PB12.GPIO_Label=COMM_CS
PB12.Signal=GPXTI12
PB13.GPIO_Label=COMM_DRDY
PB13.Signal=GPIO_Output
PB14.GPIO_Label=COMM_MISO
PB14.Signal=SPI2_MISO
PB15.GPIO_Label=COMM_MOSI
PB15.Signal=SPI2_MOSI
PB8.GPIO_Label=TESTOUT
PB8.Signal=GPIO_Output
PC10.GPIO_Label=VERSION_1
PC10.Signal=GPIO_Input
PC11.GPIO_Label=STATUS_GOOD
PC11.Signal=GPIO_Output
PC12.GPIO_Label=STATUS_BAD
PC12.Signal=GPIO_Output
PC4.GPIO_Label=VOUT_FILTERED
PC4.Signal=ADCx_IN13
PC6.GPIO_Label=COMM_CON
PC6.Signal=GPIO_Output
PD2.GPIO_Label=MUX_EN
PD2.Signal=GPIO_Output

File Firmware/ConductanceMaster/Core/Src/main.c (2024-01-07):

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
/* Includes ------------------------------------------------------------------*/
#include "main.h"
#include "usb_device.h"

/* USER CODE BEGIN Includes */
#include "usermain.h"
/* USER CODE END Includes */

ADC_HandleTypeDef hadc1;
DMA_HandleTypeDef hdma_adc1;

SPI_HandleTypeDef hspi1;
SPI_HandleTypeDef hspi2;

TIM_HandleTypeDef htim1;

void SystemClock_Config(void);
static void MX_GPIO_Init(void);
static void MX_DMA_Init(void);
static void MX_ADC1_Init(void);
static void MX_SPI1_Init(void);
static void MX_SPI2_Init(void);
static void MX_TIM1_Init(void);
/**
  * @brief  The application entry point.
  * @retval int
  */
int main(void)
{
  /* MCU Configuration--------------------------------------------------------*/

  /* Reset of all peripherals, Initializes the Flash interface and the Systick. */
  HAL_Init();

  /* Configure the system clock */
  SystemClock_Config();

  /* Initialize all configured peripherals */
  MX_GPIO_Init();
  MX_DMA_Init();
  MX_SPI1_Init();
  MX_SPI2_Init();
  MX_TIM1_Init();
  MX_USB_DEVICE_Init();
  /* USER CODE BEGIN 2 */
  MX_ADC1_Init(); // Must be called after MX_DMA_Init()
  user_main();
  /* USER CODE END 2 */

  /* Infinite loop */
  /* USER CODE BEGIN WHILE */
  while (1)
  {
    /* USER CODE END WHILE */

    /* USER CODE BEGIN 3 */
  }
  /* USER CODE END 3 */
}

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


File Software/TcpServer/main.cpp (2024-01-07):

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
#include "assertions.h"
#include "configuration.h"
#include "lockfile.h"
#include "logger.h"
#include "tcpserver.h"

#include <QCommandLineParser>
#include <QCoreApplication>
#include <QDir>

#include <csignal>

// ---------------------------------------------------------------------------------------------- //

namespace {
    TcpServer* g_tcpServer = nullptr;
}

// ---------------------------------------------------------------------------------------------- //

void catchQuitSignals()
{
    const auto unixSignals = { SIGQUIT, SIGINT, SIGTERM };

    const auto handler = [](int) {
        QCoreApplication::quit();
    };

    for (auto sig : unixSignals)
        std::signal(sig, handler);
}

// ---------------------------------------------------------------------------------------------- //

void catchDisconnectSignal()
{
    const auto handler = [](int)
    {
        ASSERT_NOT_NULL(g_tcpServer);
        QMetaObject::invokeMethod(g_tcpServer, "disconnect", Qt::QueuedConnection);
    };

    std::signal(SIGHUP, handler);
}

// ---------------------------------------------------------------------------------------------- //

auto main(int argc, char* argv[]) -> int
{
    QCoreApplication::setOrganizationName("Bonn-Rhein-Sieg University of Applied Sciences");
    QCoreApplication::setApplicationName("ReDeX TCP Server");
    QCoreApplication::setApplicationVersion("1.0");

    QCommandLineParser parser;
    parser.setApplicationDescription("TCP interface to sensor network.");
    parser.addHelpOption();
    parser.addVersionOption();

    QCommandLineOption configOption({"c", "config"}, "Set path to configuration file.",
                                    "filename", "config.xml");
    parser.addOption(configOption);

    QCommandLineOption logfileOption({"l", "logfile"}, "Set path to log file.",
                                    "filename", "log.txt");
    parser.addOption(logfileOption);

    QCoreApplication application(argc, argv);
    parser.process(application);

    try {
        QString lockPath = QDir::temp().absoluteFilePath("redex-tcp-server.lock");
        LockFile lock(lockPath);

        Logger::setLogFile(parser.value(logfileOption));

        Configuration config(parser.value(configOption));
        DeviceManager devices(config);

        TcpServer server(config, devices);
        g_tcpServer = &server;

        catchQuitSignals();
        catchDisconnectSignal();

        QMetaObject::invokeMethod(&server, "start", Qt::QueuedConnection);

        return QCoreApplication::exec();
    }
    catch (const std::exception& e)
    {
        Logger::error(e.what());
        return -1;
    }
}

// ---------------------------------------------------------------------------------------------- //

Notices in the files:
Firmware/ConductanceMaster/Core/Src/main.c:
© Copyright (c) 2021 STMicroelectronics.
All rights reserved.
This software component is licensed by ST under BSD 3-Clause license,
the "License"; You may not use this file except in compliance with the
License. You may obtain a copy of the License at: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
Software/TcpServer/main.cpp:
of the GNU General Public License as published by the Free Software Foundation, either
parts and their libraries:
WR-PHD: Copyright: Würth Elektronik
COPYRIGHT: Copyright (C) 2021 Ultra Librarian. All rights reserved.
